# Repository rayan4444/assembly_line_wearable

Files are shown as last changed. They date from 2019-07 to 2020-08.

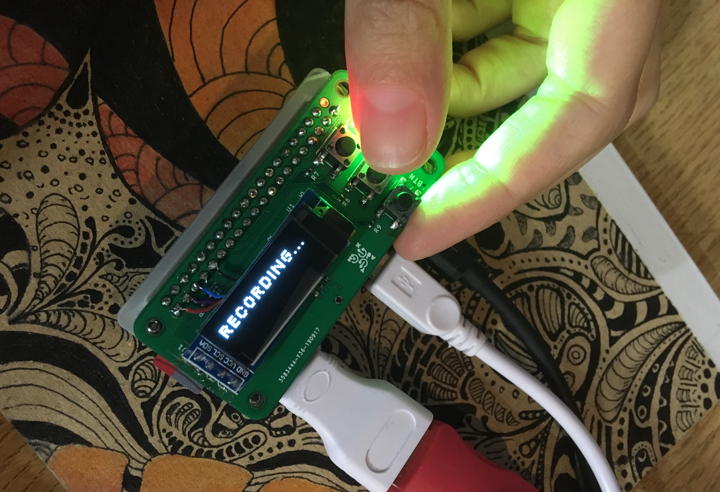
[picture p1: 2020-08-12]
assets/Crimson_testing_2.jpg

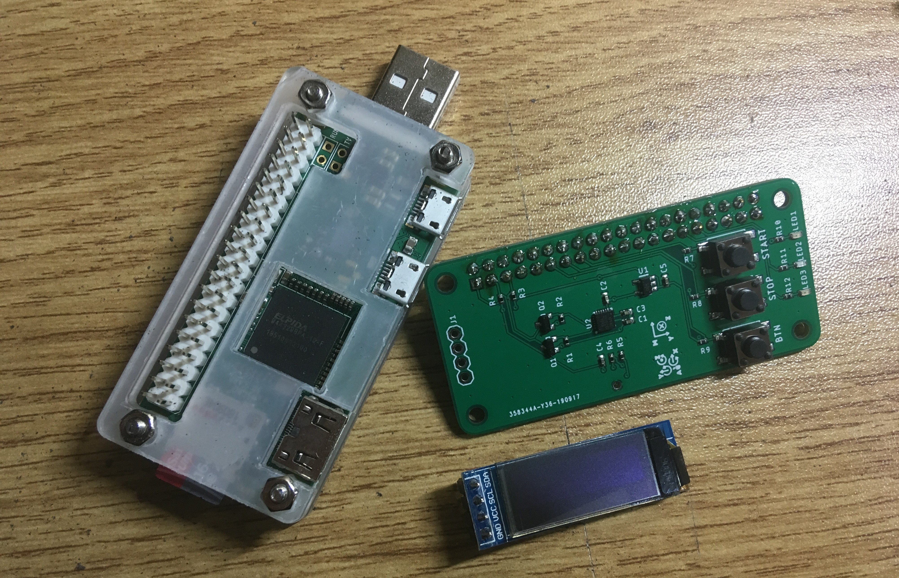
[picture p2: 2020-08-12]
assets/Crimson_testing_3.jpg

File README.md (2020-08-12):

# Crimson Dynamic

Hardware files and code for Crimson Dynamic (HAX Shenzhen 2019) sensor system prototyping

## Objective
Design a sensor system that adds value to the exoskeleton, specifically for use in an overhead assembly line in car factories. Potential insights the sensor system could provide:
* Task compliance: ensure a worker did not forget a bolt/nut on a car
* long term vibration exposure
* long term arm fatigue
* long term noise exposure
 * etc.

## REV 1
Sensor breakout to count the number of overhead drilling actions accomplished. Looked into doing an FFT analysis on IMU data and microphone data. Decided to settle on matching IMU data peaks to microphone data peaks. The same two sensors could be use to quantify the long term exposure to vibration, noise and fatigue.

## REV2
Pi HAT with sensors and UI to count the number of overhead drilling actions accomplished. A more efficient rendition of REV1 that is usable for demonstration.
> Note: Data is post processed and results are not given in real time

## REV3
NRF52 based sensor node with only IMU to monitor limb motion and vibration

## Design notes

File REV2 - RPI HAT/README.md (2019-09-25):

Crimson Dynamics REV2

## Description
Pi HAT with sensors and UI to count the number of overhead drilling actions accomlished:
- 1 x ICM20948 9-Dof IMU 
- 1 x SPH0645LM4H MEMS Microphone
- 3 x pushbuttons
- 2 x LEDs
- 1 x 128x32 I2C OLED Display 
- 1 x Raspberry Pi Zero W v1.1

#### Python scripts
Crimson_button.py runs at boot and imports functions from Crimson_data_log.py and Crimson_action_count.py

#### Usage:
- Boot up the Rasberry Pi and wait for the OLED display to refresh. This might take up to 3-4 min.  
- Pressing "start" button records 40s of data from the microphone and the IMU (x,y,z acceleration to be specific). 
- Green LED lights up and stays on after the recording is done if everything went well 
- Pressing "stop" button analyses results, using the latest action counting technique from rev1.
> By default plotting is not enabled because it slows everything down and requires a way to close the plot window to proceed. but in case it is needed, plt.show() can be uncommented from Crimson_action_count.py
- Orange LED lights up and stays on after processing is done if everything went well. The final count will show on the display for a couple seconds. 
- Pressing "BTN" button deletes all data records. If you want to keep the recorded data, ssh into the Rpi and copy it to another directory before deleting it. 
> If you don't delete the data, the next recording will just be appended to the current file and give false action count results. 

#### Notes: 
- Display breakout on the PCB doesn't match the module we purchsed so some reworking had to be done to be able to wire it properly 
- A single python script that can be run from boot. It imports functions from two other python files. These functions are very similar to the REV1 code, a little has been done to optimise it. 
- To view code outputs you can hook up a display to the pi or ssh into it (or use VNC). You can also uncomment print statements in the code to track the action countinfg process. 
- [Tutorial to change microphone sensitivity](https://learn.adafruit.com/adafruit-i2s-mems-microphone-breakout/raspberry-pi-wiring-and-test)

## Hardware files
Eagle files and gerber files for the Pi HAT

## Other files
* Notes from meeting with Bunnie on 24.09.2019, discussing how to go about improving the current demo and going about the next version

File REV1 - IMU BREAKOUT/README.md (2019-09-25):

Crimson Dynamics REV1

## Decription
Tries to detect drilling acitons by matching accelerometer peaks to microphone peaks. 
- Attempted doing it purely by placing the IMU on the hand holding the drill and running FFT but as the body acted as a low pass filter and filetered out higher frequencies that could have had information to characterise drilling vibrations. 
- Decided to addd a microphone to provide a second input. 
- In the final iteration of REV1, a simple peak finding algorithm from signal.scipy library is used to identify peaks in accelration and microphone recording. If the peaks happen within a second from each other they are assumed to belong to the same drilling action. Assuming the worker only does drilling tasks, this can be used to count the number of tasks. 

#### Notes:
- detailed assumptions in code
- sigle movements (vs vibrations) are not counted as drilling motion reducing false positives. 
- the code is in different scripts and run very slowly. 

## Hardware files 
ICM20948 breakout board slightly modified from the [Sparkfun one](https://www.sparkfun.com/products/15335)
## Python scripts 
#### Crimson_data_log.py
Records 10s of IMU and Microphone data, saves it in files "sensor_log.csv" and "output.wav" respectively. Later splits sensor log in "ax.csv", "ay.csv" and "az.csv" for further analysis. 

#### Crimson_action_count.py
- Opens data files and runs peak finding algorithm 
- Plots peaks found 
- For each of ax, ay, az and mic data, groups peaks that are within 0.5 seconds of each other as belonging to one "action" 
- To reduce the occurrance of false positives, only considers "actions" with peaks in at least two of the 3 accelerometer axes. 
- Only Counts "actions" with peaks in both microphone and accelerometer data (peak cluster averages within 1s of each other) 
- Prints total numberof valid "actions"

## OLD CODE
All the other python scripts used to test various things, such as IMU and microphone recording, data hadnling and plotting, FFT analysis etc. 

## TEST DATA
Data recorded with the prototype and used to tweak the peak finidng algorithm. TEST 5 is the best. 
In this version:
- 1 x ICM20948 9-Dof IMU (Eagle files for the breakout board are in this folder) 
- 1 x SPH0645LM4H MEMS Microphone breakout (from taobao)
- 1x Raspberry Pi (Raspberry Pi Zero W v1.1 used in my tests)

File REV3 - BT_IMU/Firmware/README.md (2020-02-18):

# Programming Guide
Notes and steps to follow to easily program the CRIMSON_IMU_BT board.

## Pinout
| Signal | NRF52 Pin |
|:---:|:---:|
|LED_R|P0.13|
|LED_G|P0.15|
|LED_B|P0.17|
|SCL|P.019|
|SDA| P0.18|
|IMU_INT|P0.25|
|SPI_MOSI|P0.27|
|SPI_MISO|P0.26|
|SPI_SCK|P0.28|
|SPI_CS|P0.29|
|CARD_DETECT|P0.23|
|TX|P0.06|
|RX|P0.08|
|CTS|P0.07|
|RTS|P0.05|
|BAT_SENSE|AIN6/P0.30|
|BUTTON|P0.14|
|RESET|P0.21|

## Flash and Debug setup
Follow the [tutorial](https://gitlab.com/hax_eng/hax-open/vs_code_setup_tutorials/tree/master/NRF52) to setup your development environment if you haven't already.
> I use ARMGCC and GDB to compile and debug, but you can choose an entirely different setup

#### Using the NRF52 Development kit to program a custom board
You can use the onboard J-link adapter of the NRF52 Development Kit to program your custom board.

**Connections**

|NRF52 Dev Kit| Custom PCB|
|:---:|:---:|
|VTG|3V3|
|SWDIO|SWDIO|
|SWCLK|SWCLK|
|GND|GND|
|RESET*|RESET*|

\* Optional
>Make sure you power your Custom board from an external source. The VTG connection  from the Dev Kit does not power the board, it just detects the target voltage.

## Directions of use
* Power on or reset device: a pink LED will stay on until you connect and pair with a Bluetooth host (ex: your smartphone. you can use NRFconnect mobile app).
* Once the device is connected and paired, the light will turn blue. 
* Stand in a neutral position with the arm down. Press the button to calibrate the device: this will sync time and record gyro offsets. 
* Once the device is calibrated, you can go a head and use it: it will log "up" and "down" events in the SD card. 

## Feature implementation
Already implemented:
* BLE connection
* Time sync
* Reading sensor data
* Processing sensor data (Madgwick filter) to determine orientation
* Logging "up" (event type 1) and "down"  (event type 0) events with timestamp
* Writing events to SD card
* Reading battery ADC

To be implemented:
* Read SD card file over UART
* Read SD card file over BLE
* Monitor battery charging 
* Battery level service over BLE

Notes:
* The device updates roll pitch and yaw angles with reference to earth gravity so you can create more event types by defining specific angle thresholds. 

## Errata

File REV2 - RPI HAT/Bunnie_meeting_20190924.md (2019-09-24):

# Crimson <> Bunnie meeting (24/09/2019)

## How to improve python running on Rpi zero (faster, less resource intensive)
* Pickling (https://pythontips.com/2013/08/02/what-is-pickle-in-python/)
* Microphone: Reduce sample count to 8kHz for microphone, record in mono
* Pre-compile python

Basically spend a bunch of time optimising your python code.

## Real time? 
Live counting with python: if you do live stream processing you need at least 2 cores, one for sampling , one for processing)

## If you want to add AI for fanciness: 
* Google AI kit: https://www.blog.google/technology/ai/introducing-aiy-vision-kit-make-devices-see/
* Pi HAT format train drill sound as a “attention word” 
* You can train it on different tools (microphone data and maybe even IMU?)

## IOT approach vs processing everythign locally 
* everything on the glove, it’s self contained: porting python to a more contained MCU might be difficult, strong-ish processor needed that's going to be on the more expensive side. 

vs 

* ioT : (more potential problems having a whole server infrastructure, antenna/electrical interference etc….)> hidden costs. So if your team is not especially strong in IOT going that route is not recommended. It might end up costing you a lot more than the self contained solution

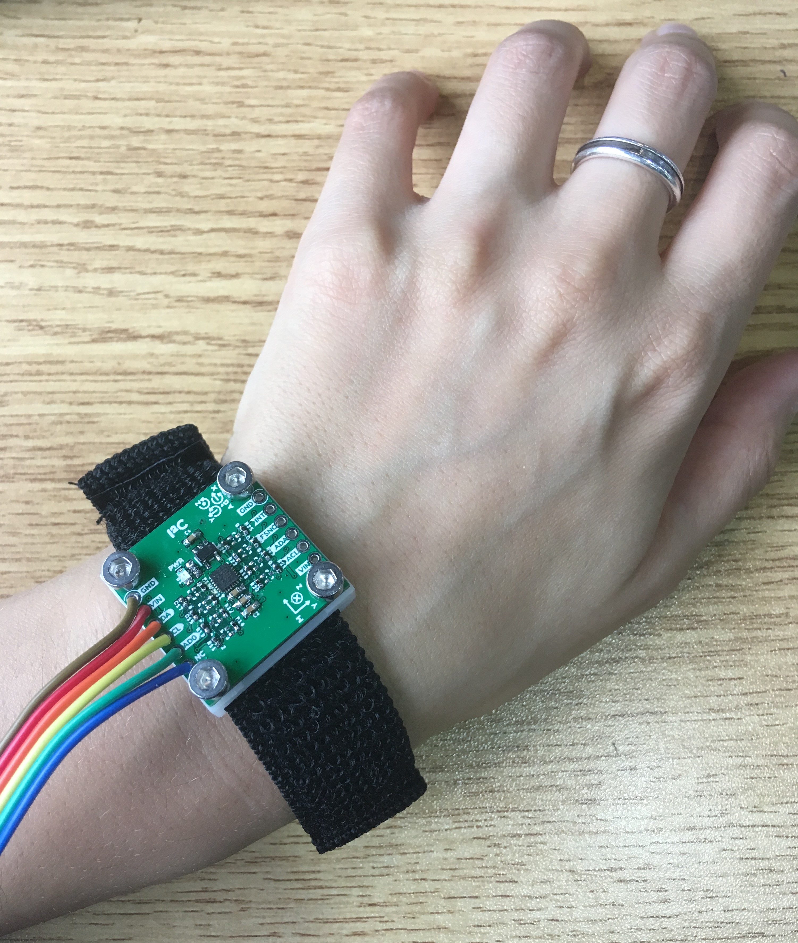
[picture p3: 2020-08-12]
assets/Crimson_breakout_1.jpg

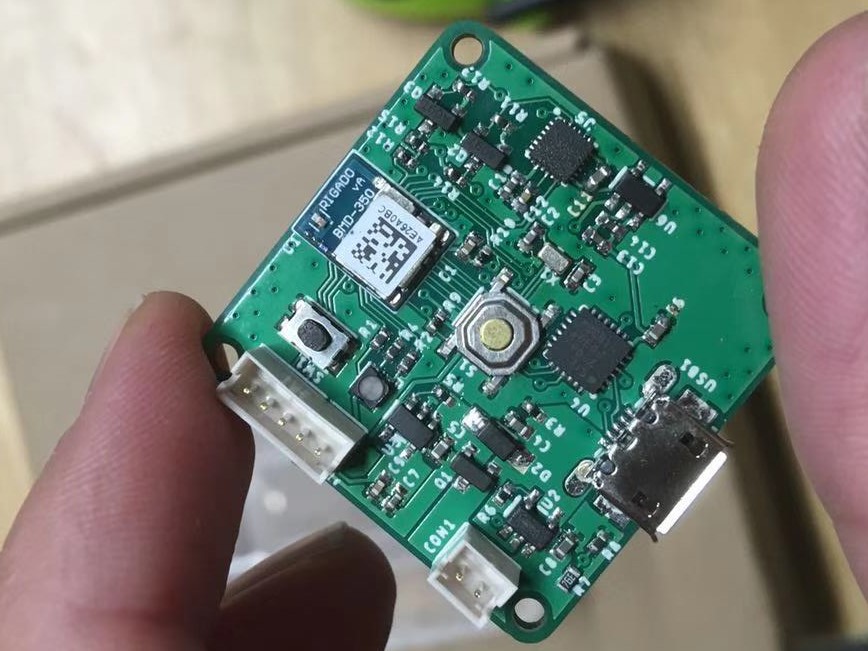
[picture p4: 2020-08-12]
assets/bt_imu.jpg

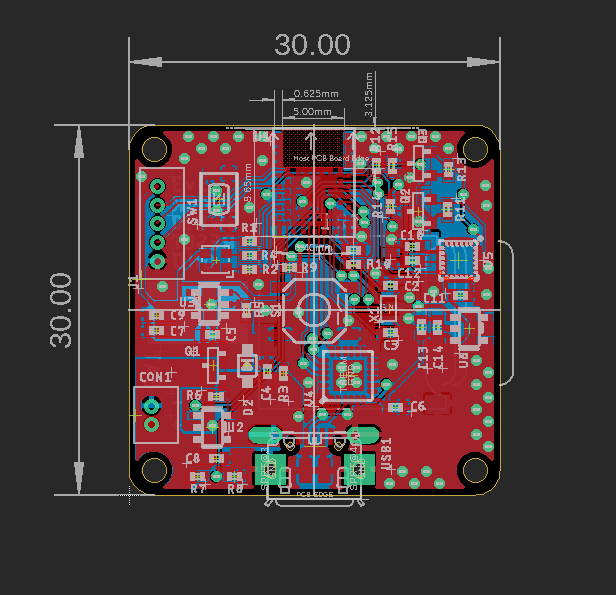
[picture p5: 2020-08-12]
assets/layout.png

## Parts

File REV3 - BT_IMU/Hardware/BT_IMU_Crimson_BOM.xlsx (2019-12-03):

Crimson BT_IMU BOM
# | Parts | Value | Qty | Package | Description | Link
1 | C1, C9, C11, C12 | 100nF | 4 | C0402 | Ceramic Capacitor | https://item.szlcsc.com/107424.html
2 | C2, C3 | 22pF | 2 | C0402 | Ceramic Capacitor | https://item.szlcsc.com/1907.html
3 | C4, C5, C6, C8 | 10uF | 4 | C0402 | Ceramic Capacitor | https://item.szlcsc.com/88326.html
4 | C7, C10, C13, C14 | 1uF | 4 | C0402 | Ceramic Capacitor | https://item.szlcsc.com/93949.html
5 | R1, R2, R4 | 100R | 3 | R0402 | Resistor | https://item.szlcsc.com/25881.html
6 | R6 | 2k | 1 | R0402 | Resistor | https://item.szlcsc.com/399955.html
7 | R7 | 6M | 1 | R0402 | Resistor | https://item.szlcsc.com/415864.html
8 | R8 | 2.2M | 1 | R0402 | Resistor | https://item.szlcsc.com/26832.html
9 | R3, R5 | 100k | 2 | R0402 | Resistor | https://item.szlcsc.com/107449.html
10 | R9, R10, R12 | 10k | 3 | R0402 | Resistor | https://item.szlcsc.com/103974.html
11 | R11, R13, R14, R15 | 4.7k | 4 | R0402 | Resistor | https://item.szlcsc.com/26683.html
12 | D1 | B2020RGBA | 1 | B2020RGBA | RGB LED | https://item.szlcsc.com/110013.html
13 | D2 | MBR120 | 1 | SOD-123 | Schottky Diode | https://item.szlcsc.com/142169.html
14 | Q1 | DMG2305 | 1 | SOT-23 | P-Channel MOSFET | https://item.szlcsc.com/161808.html
15 | Q2, Q3 | AO3400 | 2 | SOT-23 | N-Channel MOSFET | https://item.szlcsc.com/421500.html
16 | X1 | ECX-12L or ABS06L | 1 | 2.0X1.2 | Tuning Fork Crystals (kHz) SMD:
17 | U1 | BMD-350 | 1 | BMD-350 | BMD-350
18 | U2 | MCP73831T-2ACI/OT | 1 | SOT23-5 | MCP73831/2 LIPO Charger | https://item.szlcsc.com/15551.html
19 | U3 | AP2112K-3.3TRG1 | 1 | SOT23-5 | 3.3V Fixed Voltage Regulator | https://item.szlcsc.com/52131.html
20 | U4 | CP2104 | 1 | QFN24_4MM_SMSC | USB to UART Bridge | https://item.szlcsc.com/48747.html
21 | U5 | ICM-20948 | 1 | QFN24-3X3 | 9 Degree of Freedom IMU
22 | U6 | TLV70018DDCR | 1 | MICROBUILDER_SOT23-5 | 1.8V Fixed Linear Voltage Regulator | https://item.szlcsc.com/81068.html
23 | SW1 | TS5215A 250gf | 1 | MICROBUILDER_BTN_KMR2_4.6X2.8 | Tact Switch | https://item.szlcsc.com/363186.html
24 | S1 | KMR2 | 1 | TACTILE_SWITCH_SMD_5.2MM | Tact Switch | https://item.szlcsc.com/73554.html
25 | USB1 | U254-051N-4BHJ233-S | 1 | 4UCONN_20329_V2 | USB Connectors | https://item.szlcsc.com/300259.html
26 | CON1 | B2B-ZR | 1 | B2B-ZR | JST-ZH Connector, 2Pin | https://item.szlcsc.com/174414.html
27 | J1 | B5B-ZR | 1 | B5B-ZR | JST-ZH Connector, 5 Pin | https://item.szlcsc.com/255573.html
28 | SD1 | 2908-05WB-MG | 1 | MICROSD | Micro-SD / Transflash card holder with SPI pinout | https://item.taobao.com/item.htm?id=532902605150
29 | N.A. | LiPo Battery | 1 | Lipo Battery |  | (with ZH1.25 connector) https://item.taobao.com/item.htm?id=41411659259

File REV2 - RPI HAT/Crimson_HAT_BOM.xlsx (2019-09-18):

# | Parts | Value | Qty | Package
1 | C2, C3 | 100nF | 2 | C0402 | https://item.szlcsc.com/287818.html
2 | C1, C4, C5 | 1uF | 3 | C0402 | https://item.szlcsc.com/53938.html
3 | R10, R11, R12 | 100R | 3 | R0402 | no need to buy
4 | R5, R7, R8, R9 | 10k | 4 | R0402 | https://item.szlcsc.com/26274.html
5 | R1, R2, R3, R4 | 2.2k | 4 | R0402 | no need to buy
6 | R6 | 68R | 1 | R0402 | https://item.szlcsc.com/101732.html
7 | U2 | ICM-20948 | 1 | QFN24-3X3 | https://detail.tmall.com/item.htm?id=597841363170
8 | Q1, Q2 | AO3400 | 2 | SOT-23 | https://item.szlcsc.com/192487.html
9 | LED3 | GREEN | 1 | CHIPLED_0603 | https://item.szlcsc.com/119599.html
11 | LED2 | RED | 1 | CHIPLED_0603 | https://item.szlcsc.com/193260.html
10 | IC1 | MIC_I2S_SPH0645 | 1 | SPH0645LM4H | https://item.taobao.com/item.htm?id=555562766149
13 | SW1, SW2, SW3 | SPST_TACT-EVQQ2 | 3 | EVQ-Q2 | no need to buy
14 | U1 | TLV70018DDCR | 1 | SOT23-5 | https://item.szlcsc.com/81068.html
 | SCREEN: |  |  |  | https://item.taobao.com/item.htm?id=558142276427

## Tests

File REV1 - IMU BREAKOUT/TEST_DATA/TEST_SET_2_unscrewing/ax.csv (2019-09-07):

Ax
0.93798828125
0.9345703125
0.93359375
0.92919921875
0.93603515625
0.93505859375
0.9638671875
0.935546875
0.95703125
0.97607421875
1.00244140625
1.015625
0.99365234375
1.03271484375
0.970703125
0.97802734375
1.1083984375
1.0576171875
0.96826171875
0.94970703125
0.95263671875
0.9208984375
0.80712890625
0.97509765625
0.919921875
0.8486328125
0.7021484375
0.619140625
0.67578125
0.654296875
0.69091796875
0.73974609375
0.7314453125
0.6904296875
0.66015625
0.576171875
0.55419921875
0.60693359375
0.60205078125
0.53857421875
0.59521484375
0.6015625
0.56787109375
0.546875
0.50439453125
0.548828125
0.599609375
0.59326171875
0.53955078125
0.52392578125
0.4912109375
0.46533203125
0.4443359375
0.5126953125
0.5400390625
0.38232421875
0.41748046875
0.37548828125
0.4521484375
0.4892578125
0.44921875
0.42138671875
0.4130859375
0.4052734375
0.478515625
0.3603515625
0.4267578125
0.41552734375
0.3779296875
0.43701171875
0.4296875
0.4287109375
0.43359375
0.4111328125
0.43896484375
0.130859375
0.26025390625
0.29736328125
0.115234375
0.02685546875
0.32275390625
0.30126953125
0.28271484375
0.21923828125
0.3212890625
0.35888671875
0.146484375
0.4599609375
0.54931640625
0.24365234375
0.34619140625
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

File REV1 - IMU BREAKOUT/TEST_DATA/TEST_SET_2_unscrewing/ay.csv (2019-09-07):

Ay
-0.08154296875
-0.07958984375
-0.08447265625
-0.08203125
-0.080078125
-0.08984375
-0.0830078125
-0.0947265625
-0.06396484375
-0.0771484375
-0.072265625
-0.0810546875
-0.0849609375
-0.08740234375
-0.0791015625
-0.0791015625
-0.068359375
-0.10888671875
-0.11865234375
-0.125
-0.1376953125
-0.1240234375
-0.14208984375
-0.09716796875
-0.0927734375
-0.103515625
-0.0595703125
0.0205078125
0.00390625
0.06396484375
0.06103515625
0.08203125
0.07470703125
0.1103515625
0.07421875
0.10009765625
0.11474609375
0.1337890625
0.1396484375
0.1787109375
0.1953125
0.19189453125
0.1640625
0.16015625
0.18017578125
0.1865234375
0.193359375
0.20947265625
0.22509765625
0.216796875
0.208984375
0.2177734375
0.24755859375
0.15576171875
0.23388671875
0.19775390625
0.20703125
0.21923828125
0.208984375
0.2314453125
0.21923828125
0.2373046875
0.2255859375
0.25048828125
0.255859375
0.34326171875
0.23974609375
0.23779296875
0.2734375
0.25390625
0.27392578125
0.208984375
0.21826171875
0.2177734375
0.1123046875
0.46875
0.18896484375
0.27734375
0.2890625
0.384765625
0.50830078125
0.4853515625
0.5546875
0.45556640625
0.48583984375
0.40771484375
0.43896484375
0.51318359375
0.5234375
0.37353515625
0.390625
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

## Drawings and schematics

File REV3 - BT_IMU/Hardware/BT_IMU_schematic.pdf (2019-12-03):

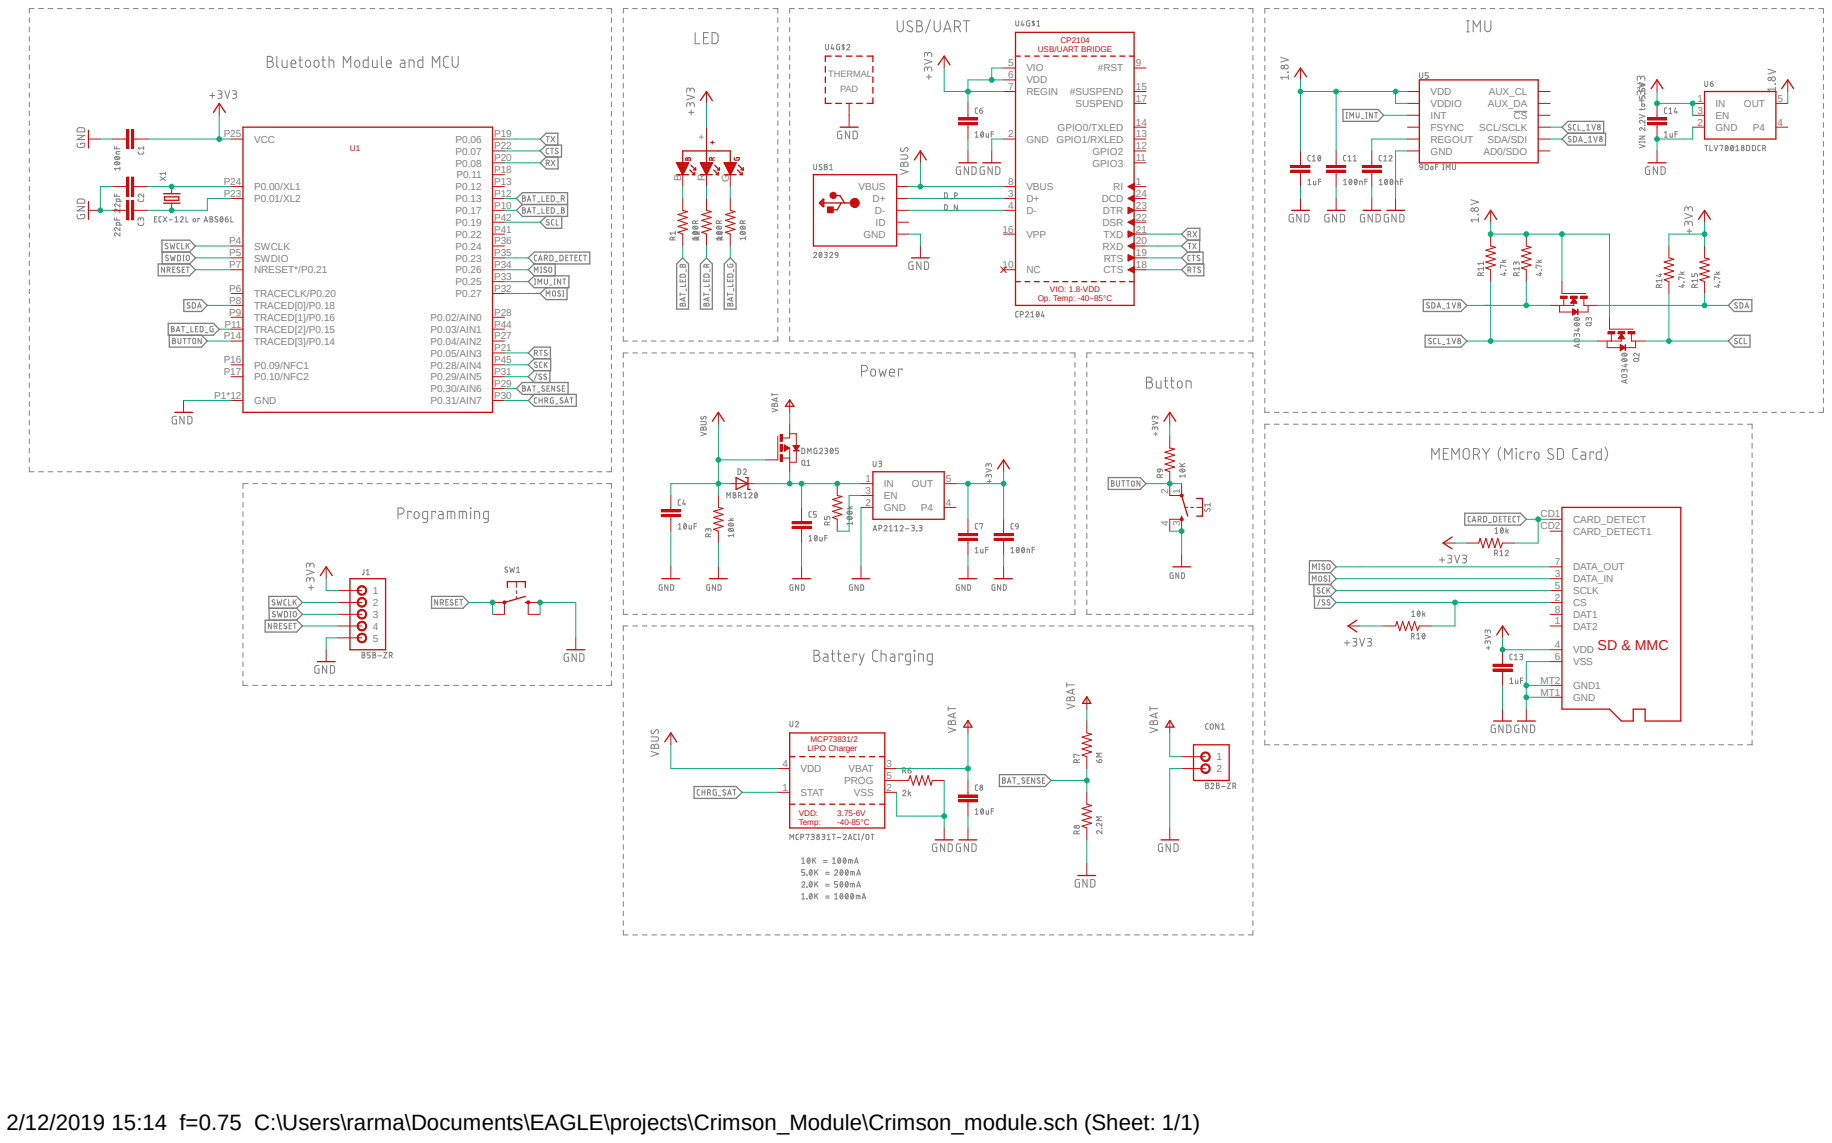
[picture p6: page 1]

2/12/2019 15:14 f=0.75 C:\Users\rarma\Documents\EAGLE\projects\Crimson_Module\Crimson_module.sch (Sheet: 1/1)

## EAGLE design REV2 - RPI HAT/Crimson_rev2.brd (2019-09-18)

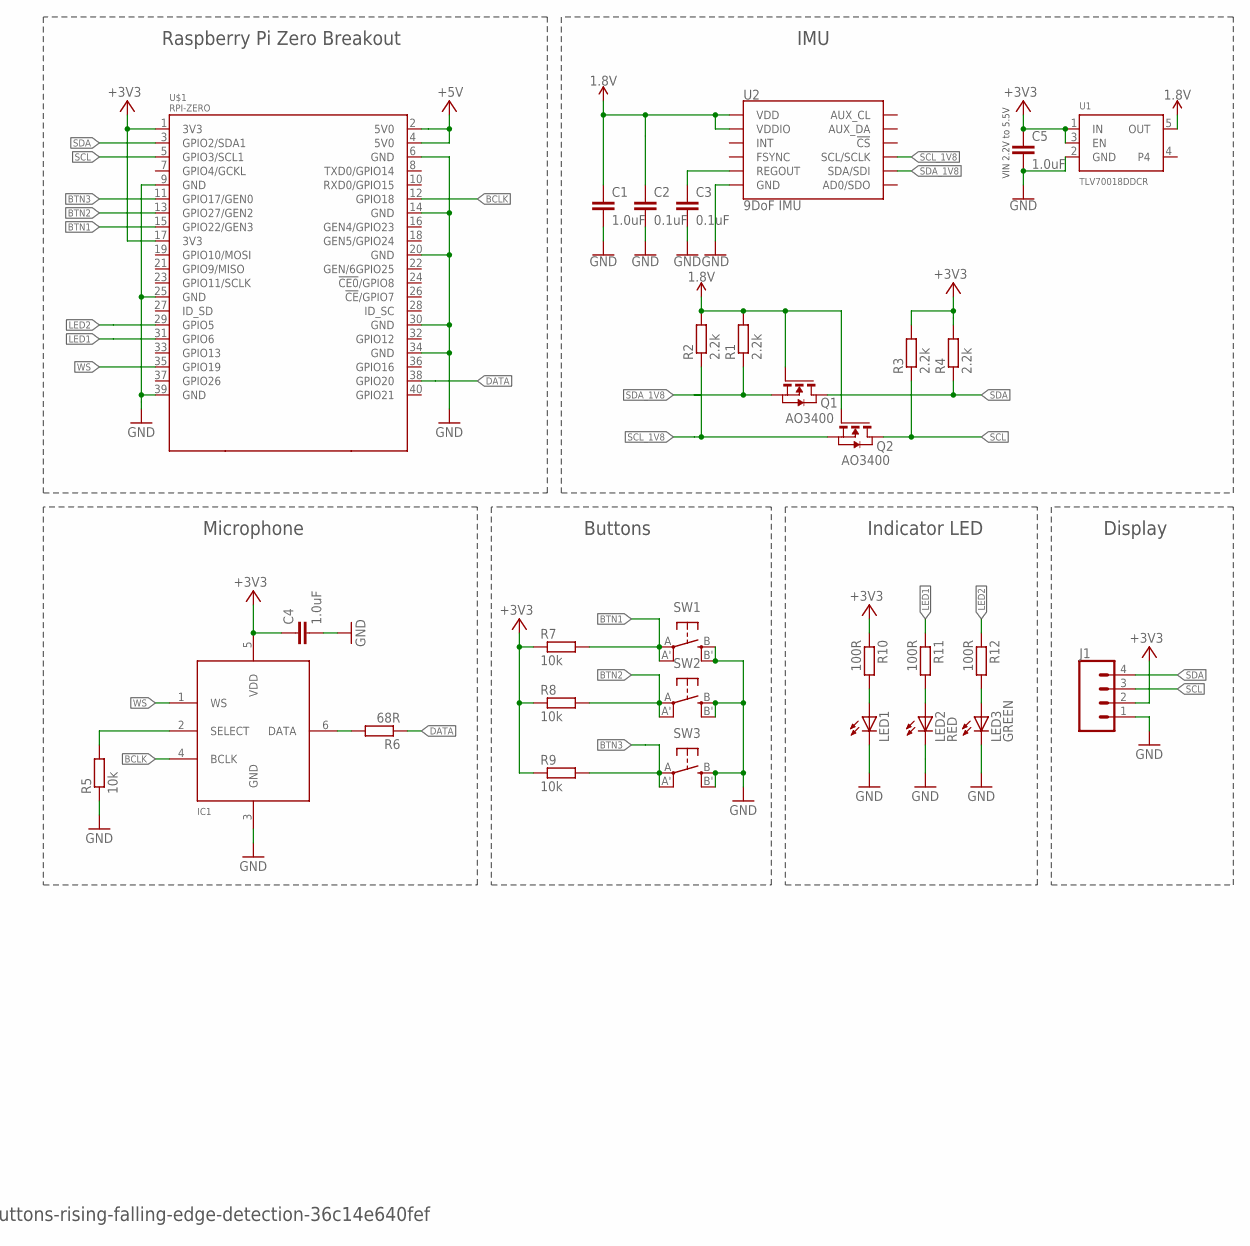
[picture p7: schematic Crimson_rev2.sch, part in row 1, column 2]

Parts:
C1, C4, C5: 1.0uF; 0402
C2, C3: 0.1uF; 0402
IC1: MIC_I2S_SPH0645; SPH0645LM4H
J1: CONN_04; 1X04
LED1: LEDCHIPLED_0603; CHIPLED_0603
LED2: RED; CHIPLED_0603
LED3: GREEN; CHIPLED_0603
Q1, Q2: AO3400; SOT-23
R1, R2, R3, R4: 2.2k; R0402
R5, R7, R8, R9: 10k; R0402
R6: 68R; R0402
R10, R11, R12: 100R; R0402
SW1, SW2, SW3: SPST_TACT-EVQQ2; EVQ-Q2
U1: TLV70018DDCR; MICROBUILDER_SOT23-5
U2: 9DoF IMU; QFN24-3X3
U$1: RPI-ZERO; RASPBERRYPI_BASTELSTUBE_V13_RASPI_BOARD_B+_FULL

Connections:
1.8V: C1.1, C2.1, Q1.G, Q2.G, R1.2, R2.2, U1.5 (OUT), U2.8 (VDDIO), U2.13 (VDD)
+3V3: C4.1, C5.1, IC1.5 (VDD), J1.2, R3.2, R4.2, R7.2, R8.2, R9.2, R10.1, U1.1 (IN), U1.3 (EN), U$1.1 (3V3), U$1.17 (3V3)
+5V: U$1.2 (5V0), U$1.4 (5V0)
BCLK: IC1.4 (BCLK), U$1.12 (GPIO18)
BTN1: R7.1, SW1.A, SW1.A' (P1), U$1.15 (GPIO22/GEN3)
BTN2: R8.1, SW2.A, SW2.A' (P1), U$1.13 (GPIO27/GEN2)
BTN3: R9.1, SW3.A, SW3.A' (P1), U$1.11 (GPIO17/GEN0)
DATA: R6.1, U$1.38 (GPIO20)
GND: C1.2, C2.2, C3.2, C4.2, C5.2, IC1.3 (GND), J1.1, LED1.C, LED2.C, LED3.C, R5.1, SW1.B (S), SW1.B' (S1), SW2.B (S), SW2.B' (S1), SW3.B (S), SW3.B' (S1), U1.2 (GND), U2.18 (GND), U2.20 (GND), U$1.6 (GND), U$1.9 (GND), U$1.14 (GND), U$1.20 (GND), U$1.25 (GND), U$1.30 (GND), U$1.34 (GND), U$1.39 (GND)
LED1: R11.1, U$1.31 (GPIO6)
LED2: R12.1, U$1.29 (GPIO5)
unnamed: C3.1, U2.10 (REGOUT)
unnamed: IC1.2 (SELECT), R5.2
unnamed: IC1.6 (DATA), R6.2
unnamed: LED1.A, R10.2
unnamed: LED2.A, R11.2
unnamed: LED3.A, R12.2
SCL: J1.3, Q2.D, R3.1, U$1.5 (GPIO3/SCL1)
SCL_1V8: Q2.S, R2.1, U2.23 (SCL/SCLK)
SDA: J1.4, Q1.D, R4.1, U$1.3 (GPIO2/SDA1)
SDA_1V8: Q1.S, R1.1, U2.24 (SDA/SDI)
WS: IC1.1 (WS), U$1.35 (GPIO19)

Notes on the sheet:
IMU
Microphone
Buttons
Display
Indicator LED
Reference: https://medium.com/@rxseger/interrupt-driven-i-o-on-raspberry-pi-3-with-leds-and-pushbuttons-rising-falling-edge-detection-36c14e640fef
VIN 2.2V to 5.5V
Raspberry Pi Zero Breakout

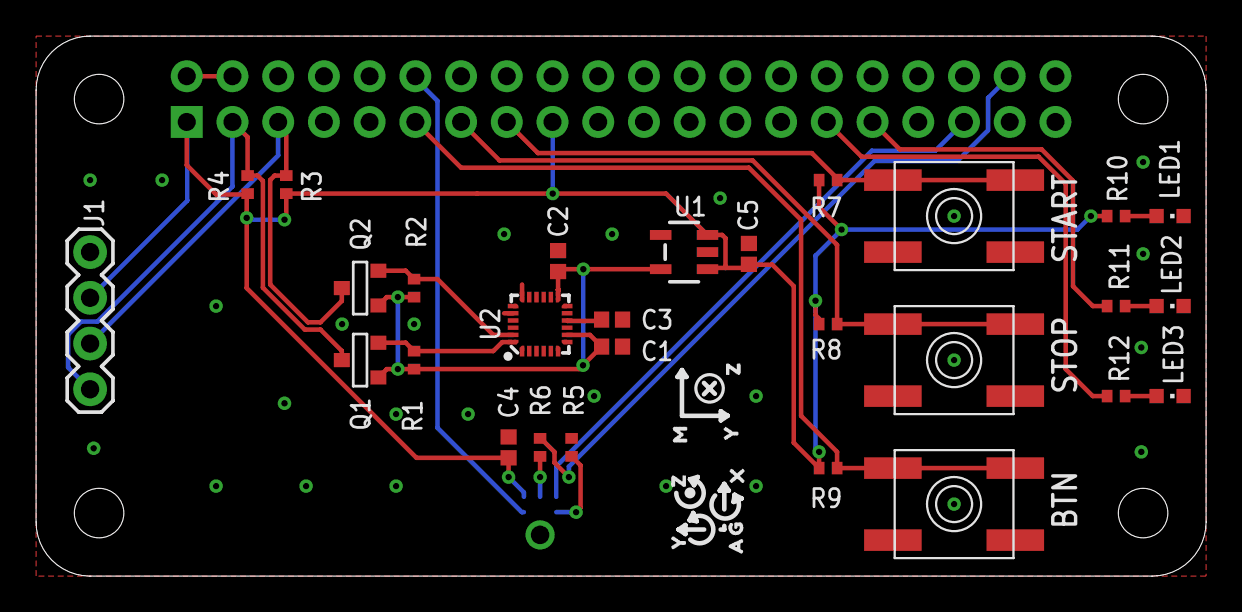
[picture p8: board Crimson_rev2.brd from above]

Board: 2 copper layers, 65.0 x 30.0 mm, 38 parts (1 on the bottom side), 22 nets.

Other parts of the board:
U$34: X0
U$35, U$41: Y1
U$36, U$42: Z2
U$37: G5
U$38: A4
U$39: M3

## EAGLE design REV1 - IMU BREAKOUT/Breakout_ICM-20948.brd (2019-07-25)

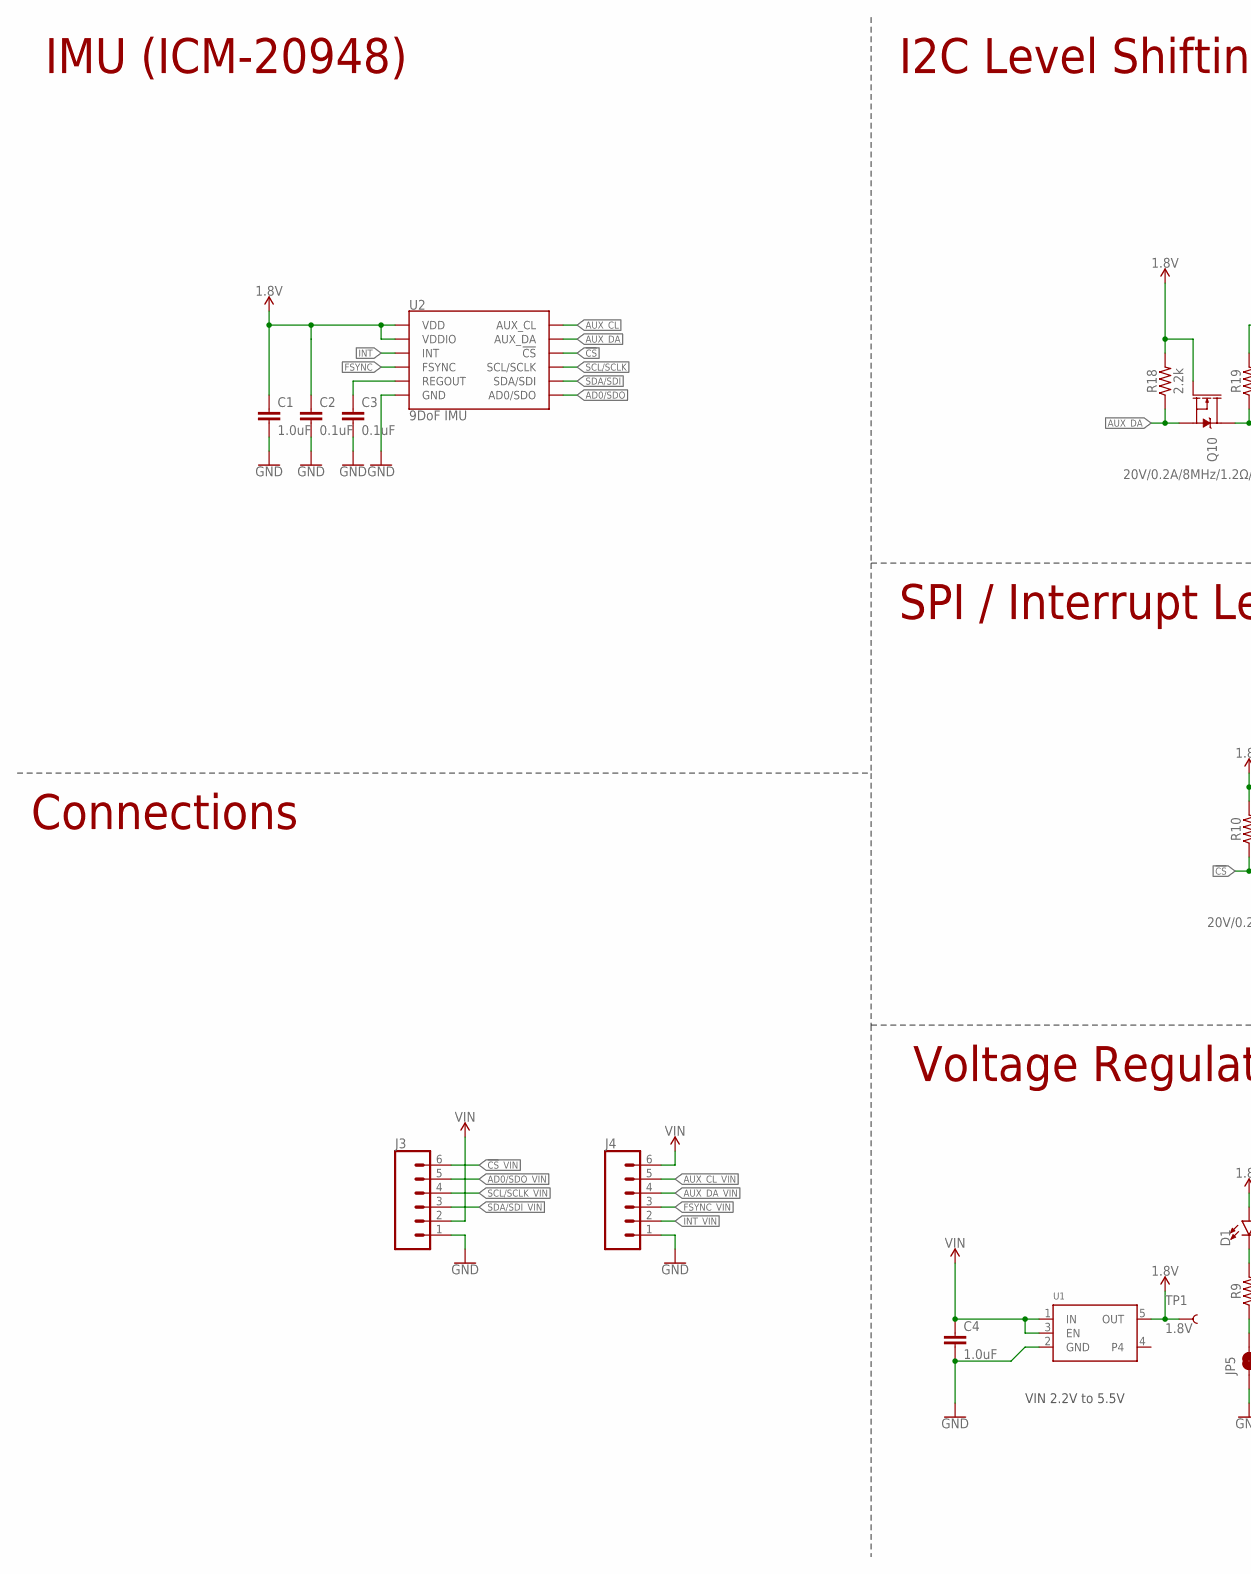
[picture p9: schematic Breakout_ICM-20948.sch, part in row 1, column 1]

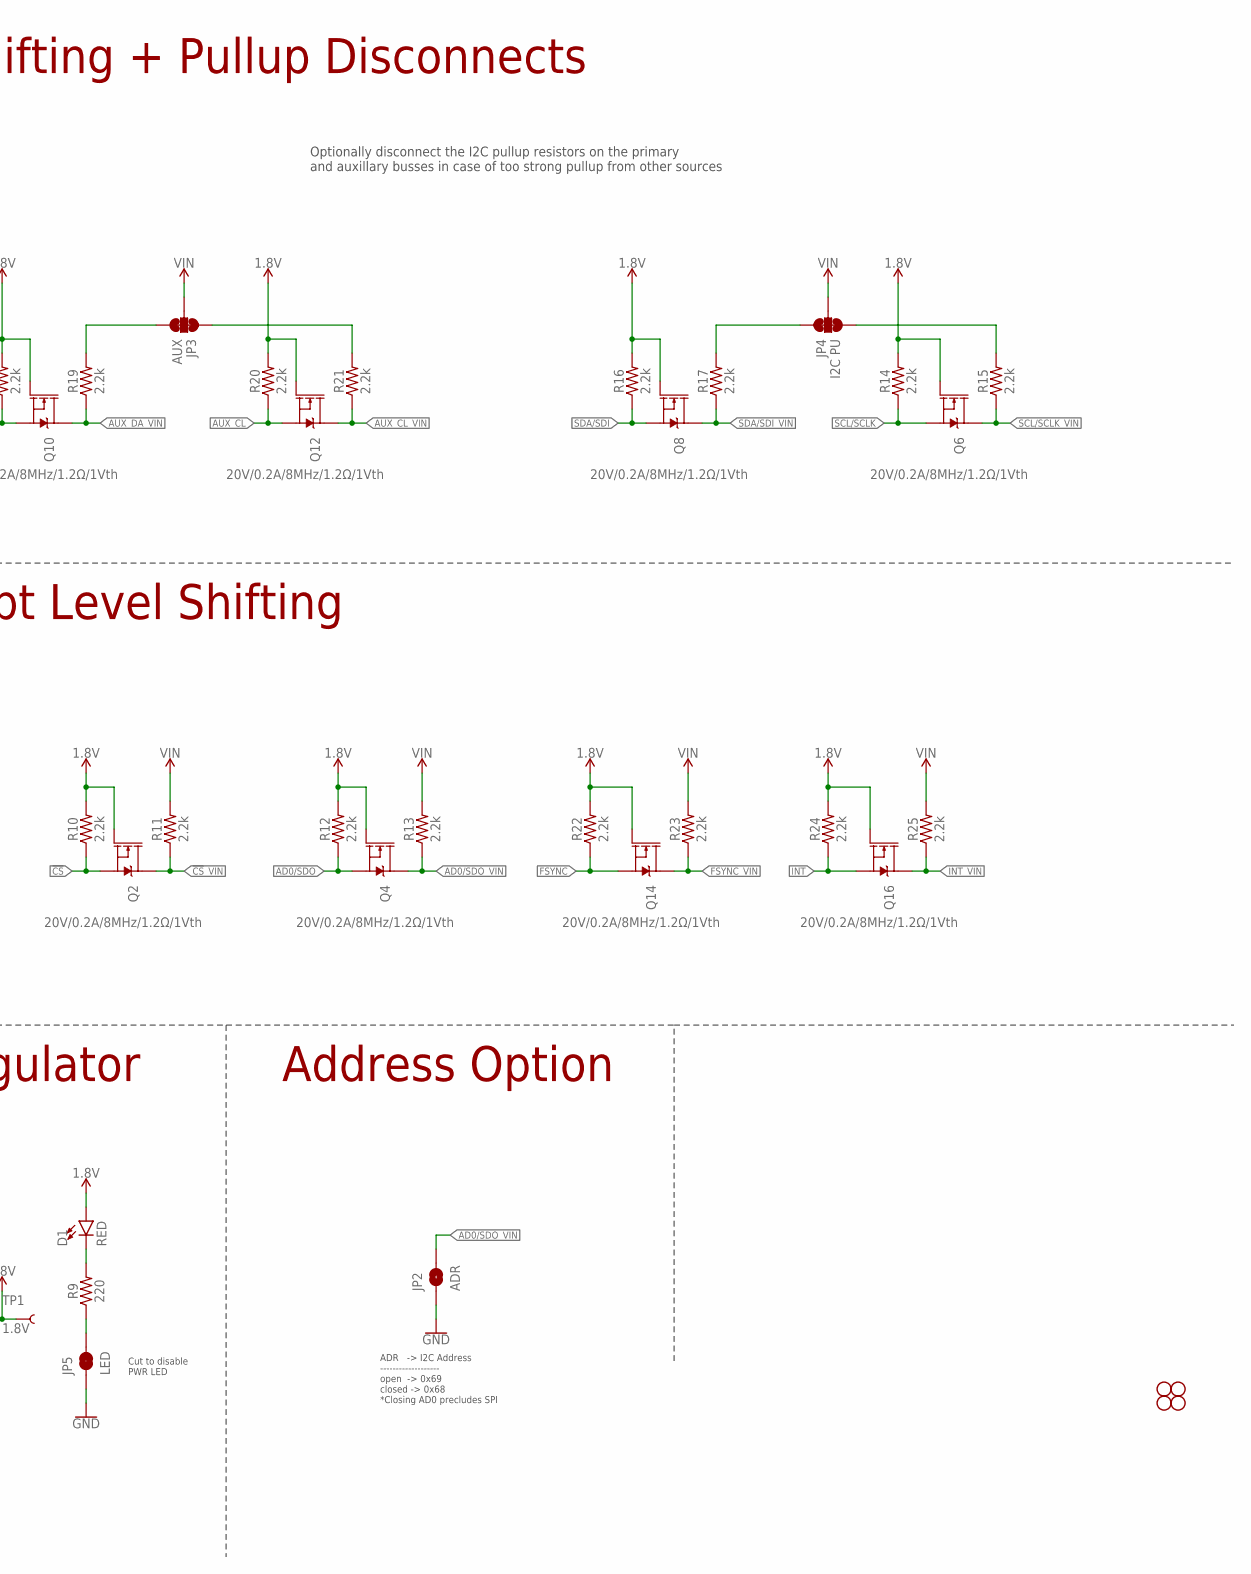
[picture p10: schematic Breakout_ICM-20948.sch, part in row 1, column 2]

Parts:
C1, C4: 1.0uF; 0603
C2, C3: 0.1uF; 0603
D1: RED; LED-0603
H1, H2, H3, H4: STAND-OFF
J3, J4: CONN_06NO_SILK_NO_POP; 1X06_NO_SILK
JP2: ADR; SMT-JUMPER_2_NO_SILK
JP3: AUX; SMT-JUMPER_3_2-NC_TRACE_SILK
JP4: I2C PU; SMT-JUMPER_3_2-NC_TRACE_SILK
JP5: LED; SMT-JUMPER_2_NC_TRACE_SILK
Q2, Q4, Q6, Q8, Q10, Q12, Q14, Q16: 20V/0.2A/8MHz/1.2Ω/1Vth; SOT-416FL
R9: 220; 0603
R10, R11, R12, R13, R14, R15, R16, R17, R18, R19, R20, R21, R22, R23, R24, R25: 2.2k; 0402-TIGHT
TP1: 1.8V; PAD.03X.03
U1: MICROBUILDER_VREG_SOT23-5; MICROBUILDER_SOT23-5
U2: 9DoF IMU; QFN24-3X3

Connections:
1.8V: C1.1, C2.1, D1.A, Q2.1 (G), Q4.1 (G), Q6.1 (G), Q8.1 (G), Q10.1 (G), Q12.1 (G), Q14.1 (G), Q16.1 (G), R10.2, R12.2, R14.2, R16.2, R18.2, R20.2, R22.2, R24.2, TP1.P$1, U1.5 (OUT), U2.8 (VDDIO), U2.13 (VDD)
!CS: Q2.2 (S), R10.1, U2.22 (!CS)
!CS!_VIN: J3.6, Q2.3 (D), R11.1
AD0/SDO: Q4.2 (S), R12.1, U2.9 (AD0/SDO)
AD0/SDO_VIN: J3.5, JP2.2, Q4.3 (D), R13.1
AUX_CL: Q12.2 (S), R20.1, U2.7 (AUX_CL)
AUX_CL_VIN: J4.5, Q12.3 (D), R21.1
AUX_DA: Q10.2 (S), R18.1, U2.21 (AUX_DA)
AUX_DA_VIN: J4.4, Q10.3 (D), R19.1
FSYNC: Q14.2 (S), R22.1, U2.11 (FSYNC)
FSYNC_VIN: J4.3, Q14.3 (D), R23.1
GND: C1.2, C2.2, C3.2, C4.2, J3.1, J4.1, JP2.1, JP5.1, U1.2 (GND), U2.18 (GND), U2.20 (GND)
INT: Q16.2 (S), R24.1, U2.12 (INT)
INT_VIN: J4.2, Q16.3 (D), R25.1
unnamed: C3.1, U2.10 (REGOUT)
unnamed: JP4.3, R15.2
unnamed: JP4.1, R17.2
unnamed: JP3.1, R21.2
unnamed: JP3.3, R19.2
unnamed: D1.C, R9.2
unnamed: JP5.2, R9.1
SCL/SCLK: Q6.2 (S), R14.1, U2.23 (SCL/SCLK)
SCL/SCLK_VIN: J3.4, Q6.3 (D), R15.1
SDA/SDI: Q8.2 (S), R16.1, U2.24 (SDA/SDI)
SDA/SDI_VIN: J3.3, Q8.3 (D), R17.1
VIN: C4.1, J3.2, J4.6, JP3.2, JP4.2, R11.2, R13.2, R23.2, R25.2, U1.1 (IN), U1.3 (EN)

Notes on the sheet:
VIN 2.2V to 5.5V
IMU (ICM-20948)
I2C Level Shifting + Pullup Disconnects
Connections
Voltage Regulator
SPI / Interrupt Level Shifting
ADR -> I2C Address ------------------- open -> 0x69 closed -> 0x68 *Closing AD0 precludes SPI
Optionally disconnect the I2C pullup resistors on the primary and auxillary busses in case of too strong pullup from other sources
Cut to disable PWR LED
Address Option

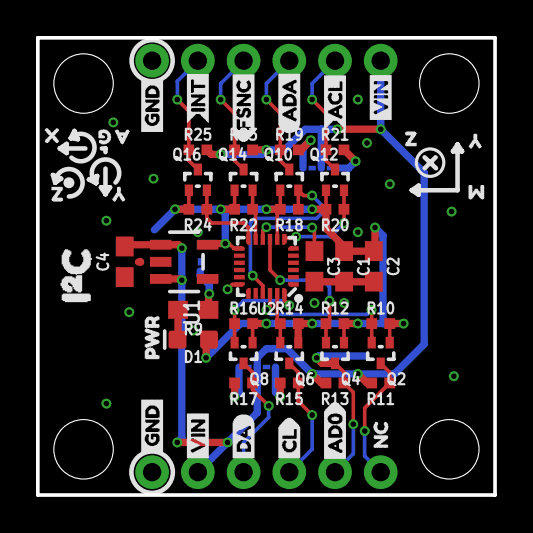
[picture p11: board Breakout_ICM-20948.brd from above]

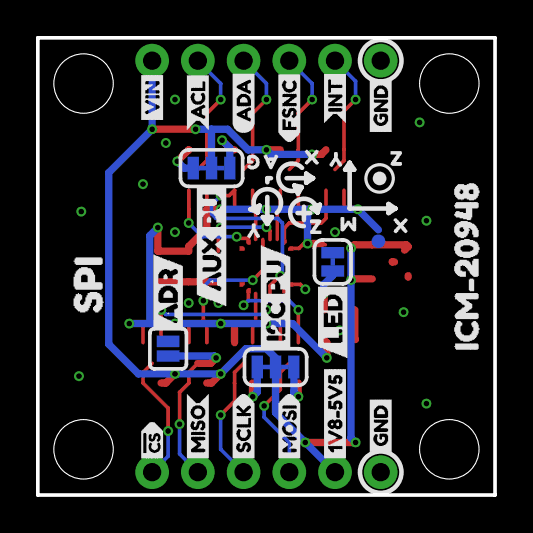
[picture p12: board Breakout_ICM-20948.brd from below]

Board: 2 copper layers, 25.4 x 25.4 mm, 92 parts (32 on the bottom side), 26 nets.

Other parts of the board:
U$1, U$2, U$22, U$24: GND4
U$3: PWR0
U$4, U$21: INT3
U$5, U$20: FSNC2
U$6, U$19: ACL1
U$7, U$18: ADA0
U$8: MISO13
U$9: MOSI14
U$10: SCLK15
U$11: #CS16
U$12: 1V8#5V57
U$13, U$30, U$44: VIN5
U$14: NC17
U$15: CL4
U$16: DA2
U$17: AD012
U$23: ADR2
U$25: I2C_PU21
U$26: SPI19
U$27: AUX_PU24
U$29: LED23
U$31: ICM#2094820
U$34, U$50, U$57: X0
U$35, U$41, U$51, U$58: Y1
U$36, U$42, U$52, U$59: Z2
U$37, U$60: G5
U$38, U$61: A4
U$39, U$49: M3
U$45: I#C1

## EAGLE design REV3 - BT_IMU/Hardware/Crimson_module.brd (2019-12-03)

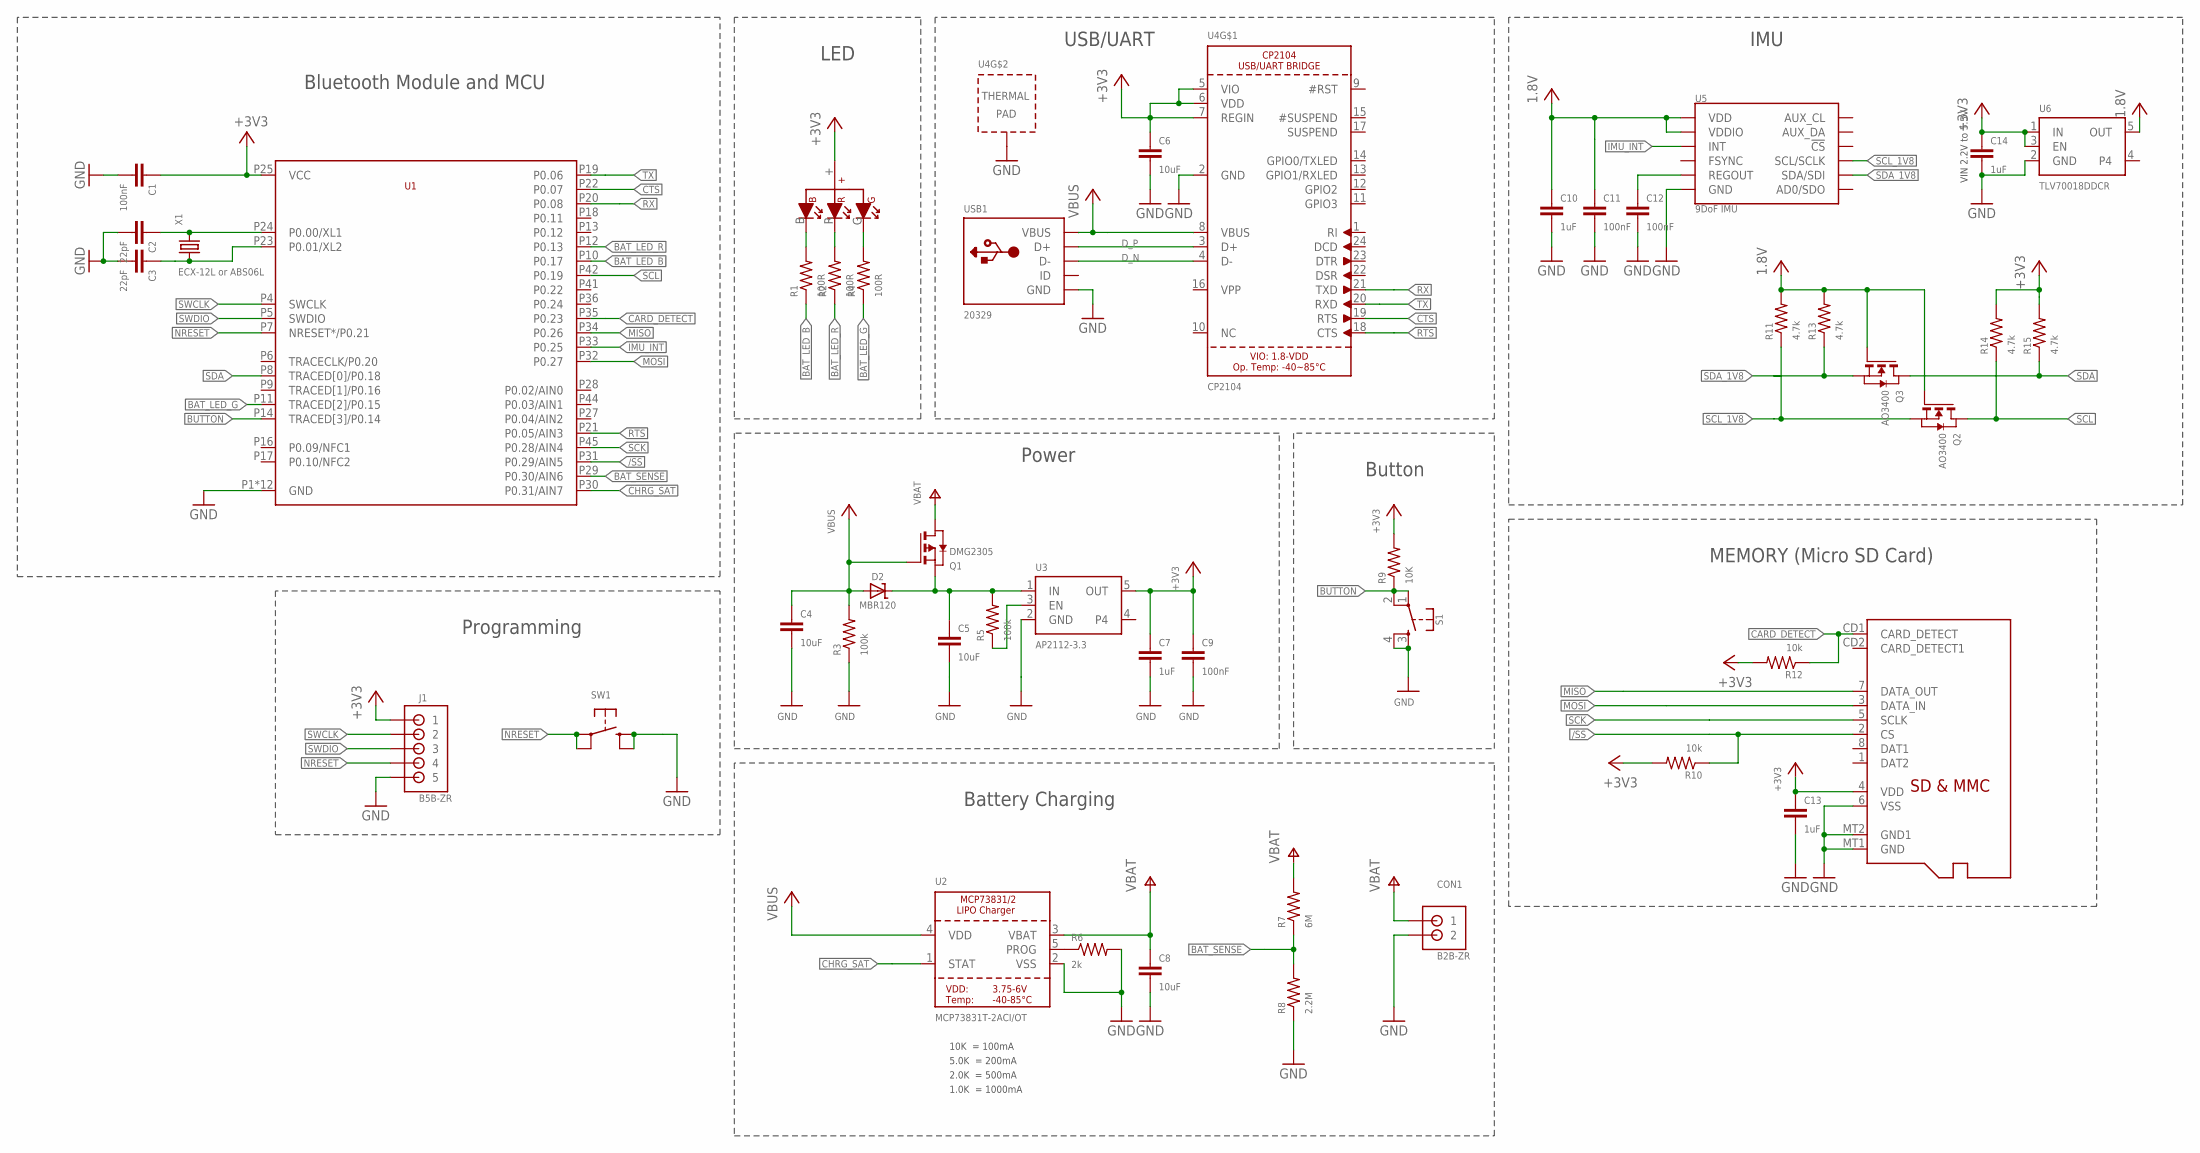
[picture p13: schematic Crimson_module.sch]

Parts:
C1, C9, C11, C12: 100nF; C0402
C2, C3: 22pF; C0402
C4, C5, C6, C8: 10uF; C0402
C7, C10, C13, C14: 1uF; C0402
CON1: B2B-ZR
D1: B2020RGBA
D2: MBR120; SOD-123
J1: B5B-ZR
Q1: DMG2305; SOT-23
Q2, Q3: AO3400; SOT-23
R1, R2, R4: 100R; R0402
R3, R5: 100k; R0402
R6: 2k; R0402
R7: 6M; R0402
R8: 2.2M; R0402
R9: 10K; R0402
R10, R12: 10k; R0402
R11, R13, R14, R15: 4.7k; R0402
S1: MOMENTARY-SWITCH-SPST-2-SMD-5.2MM; TACTILE_SWITCH_SMD_5.2MM
SD1: MICROSD
SW1: MICROBUILDER_SWITCH_TACT_SMT4.6X2.8; MICROBUILDER_BTN_KMR2_4.6X2.8
U1: BMD-350
U2: MCP73831T-2ACI/OT; SOT23-5
U3: AP2112-3.3; SOT23-5
U4: CP2104; QFN24_4MM_SMSC
U5: 9DoF IMU; QFN24-3X3
U6: TLV70018DDCR; MICROBUILDER_SOT23-5
USB1: 20329; 4UCONN_20329_V2
X1: ECX-12L or ABS06L; 2.0X1.2

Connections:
+3V3: C1.1, C6.1, C7.1, C9.1, C13.1, C14.1, D1.+, J1.1, R9.2, R10.2, R12.2, R14.2, R15.2, SD1.4 (VDD), U1.P25 (VCC), U3.5 (OUT), U4.5 (VIO), U4.6 (VDD), U4.7 (REGIN), U6.1 (IN), U6.3 (EN)
+5V: C4.1, D2.A, Q1.G, R3.2, U2.4 (VDD), U4.8 (VBUS), USB1.VBUS
/SS: R10.1, SD1.2 (CS), U1.P31 (P0.29/AIN5)
BAT_LED_B: R1.1, U1.P10 (P0.17)
BAT_LED_G: R4.1, U1.P11 (TRACED[2]/P0.15)
BAT_LED_R: R2.1, U1.P12 (P0.13)
BAT_SENSE: R7.1, R8.2, U1.P29 (P0.30/AIN6)
BUTTON: R9.1, S1.1, S1.2, U1.P14 (TRACED[3]/P0.14)
CARD_DETECT: R12.1, SD1.CD1 (CARD_DETECT), U1.P35 (P0.23)
CHRG_SAT: U1.P30 (P0.31/AIN7), U2.1 (STAT)
CTS: U1.P22 (P0.07), U4.19 (RTS)
D_N: U4.4 (D-), USB1.D-
D_P: U4.3 (D+), USB1.D+
EN: R5.1, U3.3 (EN)
GND: C1.2, C2.2, C3.2, C4.2, C5.2, C6.2, C7.2, C8.2, C9.2, C10.2, C11.2, C12.2, C13.2, C14.2, CON1.2, J1.5, R3.1, R6.2, R8.1, S1.3, S1.4, SD1.6 (VSS), SD1.MT1 (GND), SD1.MT2 (GND1), SW1.B (S), SW1.B' (S1), U1.P1 (GND), U1.P2 (GND), U1.P3 (GND), U1.P15 (GND), U1.P26 (GND), U1.P37 (GND), U1.P38 (GND), U1.P39 (GND), U1.P40 (GND), U1.P43 (GND), U1.P46 (GND), U1.P47 (GND), U2.2 (VSS), U3.2 (GND), U4.2 (GND), U4.THERM (TP), U5.18 (GND), U5.20 (GND), U6.2 (GND), USB1.BASE@1 (GND), USB1.BASE@2 (GND), USB1.GND, USB1.SPRT@1 (GND), USB1.SPRT@2 (GND), USB1.SPRT@3 (GND), USB1.SPRT@4 (GND)
IMU_INT: U1.P33 (P0.25), U5.12 (INT)
MISO: SD1.7 (DATA_OUT), U1.P34 (P0.26)
MOSI: SD1.3 (DATA_IN), U1.P32 (P0.27)
unnamed: R6.1, U2.5 (PROG)
unnamed: C12.1, U5.10 (REGOUT)
unnamed: C3.1, U1.P23 (P0.01/XL2), X1.1
unnamed: D1.B, R1.2
unnamed: D1.R, R2.2
unnamed: D1.G, R4.2
unnamed: C2.1, U1.P24 (P0.00/XL1), X1.2
unnamed: C5.1, D2.C, Q1.S, R5.2, U3.1 (IN)
NRESET: J1.4, SW1.A, SW1.A' (P1), U1.P7 (NRESET*/P0.21)
RTS: U1.P21 (P0.05/AIN3), U4.18 (CTS)
RX: U1.P20 (P0.08), U4.21 (TXD)
SCK: SD1.5 (SCLK), U1.P45 (P0.28/AIN4)
SCL: Q2.D, R14.1, U1.P42 (P0.19)
SCL_1V8: Q2.S, R11.1, U5.23 (SCL/SCLK)
SDA: Q3.D, R15.1, U1.P8 (TRACED[0]/P0.18)
SDA_1V8: Q3.S, R13.1, U5.24 (SDA/SDI)
SWCLK: J1.2, U1.P4 (SWCLK)
SWDIO: J1.3, U1.P5 (SWDIO)
TX: U1.P19 (P0.06), U4.20 (RXD)
V+: C8.1, CON1.1, Q1.D, R7.2, U2.3 (VBAT)
VCC: C10.1, C11.1, Q2.G, Q3.G, R11.2, R13.2, U5.8 (VDDIO), U5.13 (VDD), U6.5 (OUT)

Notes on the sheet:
10K = 100mA
5.0K = 200mA
2.0K = 500mA
1.0K = 1000mA
Battery Charging
Bluetooth Module and MCU
LED
USB/UART
Power
Button
MEMORY (Micro SD Card)
IMU
VIN 2.2V to 5.5V
Programming

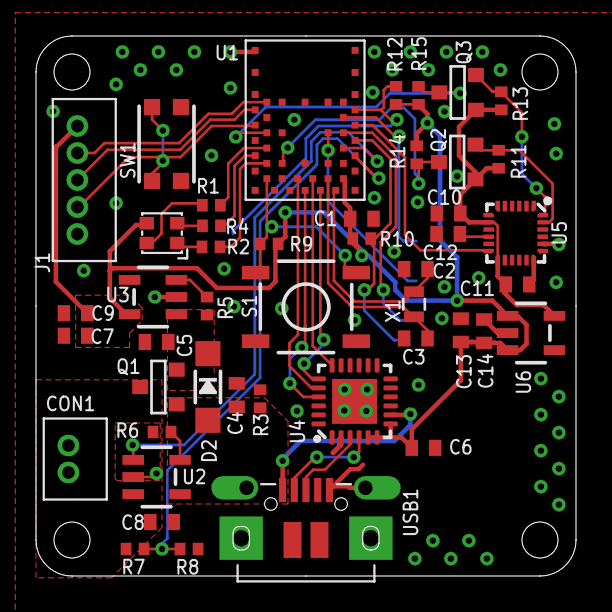
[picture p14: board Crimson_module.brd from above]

Board: 2 copper layers, 30.0 x 30.0 mm, 47 parts (1 on the bottom side), 39 nets.

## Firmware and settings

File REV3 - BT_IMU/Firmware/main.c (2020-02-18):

/**
 * Copyright (c) 2014 - 2019, Nordic Semiconductor ASA
 *
 * All rights reserved.
 *
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
 * 3. Neither the name of Nordic Semiconductor ASA nor the names of its
 *    contributors may be used to endorse or promote products derived from this
 *    software without specific prior written permission.
 *
 * 4. This software, with or without modification, must only be used with a
 *    Nordic Semiconductor ASA integrated circuit.
 *
 * 5. Any software provided in binary form under this license must not be reverse
 *    engineered, decompiled, modified and/or disassembled.
 *
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
 */
/** @file
 *
 * @defgroup ble_sdk_uart_over_ble_main main.c
 * @{
 * @ingroup  ble_sdk_app_nus_eval
 * @brief    UART over BLE application main file.
 *
 * This file contains the source code for a sample application that uses the Nordic UART service.
 * This application uses the @ref srvlib_conn_params module.
 */


#include <stdint.h>
#include <string.h>
#include "nordic_common.h"
#include "nrf.h"
#include "sdk_config.h"
#include "crimson_ble.h"
#include "app_timer.h"
#include "app_uart.h"
#include "app_util_platform.h"
#include "nrf_pwr_mgmt.h"

#include "nrf_drv_twi.h"
#include "nrf_delay.h"
#include "custom_board.h"
#include "nrf_queue.h"
#if defined (UART_PRESENT)
#include "nrf_uart.h"
#endif
#if defined (UARTE_PRESENT)
#include "nrf_uarte.h"
#endif

#include "nrf_log.h"
#include "nrf_log_ctrl.h"
#include "nrf_log_default_backends.h"

#include "nrf_drv_saadc.h"

#include "icm20948.h"
#include "crimson_sdcard.h"
#include "MadgwickAHRS.h"
#include "nrf_calendar.h"

extern uint32_t year, month, day, hour, minute, second;
extern volatile bool time_synced; 

#define ICM20948_ADDR 0x68

#define UART_TX_BUF_SIZE                256                                         /**< UART TX buffer size. */
#define UART_RX_BUF_SIZE                256                                         /**< UART RX buffer size. */
#define QUEUE_SIZE                      3

typedef enum arm_position{
    UP_POSITION,
    DOWN_POSITION,
    OTHER_POSITION
}arm_position;

arm_position previous_position; 

volatile bool log_available= false; 
volatile bool new_data_ready = false;
volatile bool m_xfer_done;

#define SAMPLES_IN_BUFFER 1
static nrf_saadc_value_t m_buffer[SAMPLES_IN_BUFFER];

#define TWI_INSTANCE_ID     0
nrf_drv_twi_t m_twi = NRF_DRV_TWI_INSTANCE(TWI_INSTANCE_ID);

#define IMU_SAMPLE_TIMER_INTERVAL     APP_TIMER_TICKS(100)     // 100 ms intervals 
APP_TIMER_DEF(imu_sample_timer_id);

float dt = 0.01; // time between two measurements 
float ax_accumulator, ay_accumulator, az_accumulator, gx_accumulator, gy_accumulator, gz_accumulator; //moving average filter accumulators

float angles[3]; // roll, pitch, yaw
float event_time= 12.3;
//circular buffer to store sensor data before running average filter
//the queue will overflow when it is full 
NRF_QUEUE_DEF(float, m_ax_queue, QUEUE_SIZE, NRF_QUEUE_MODE_OVERFLOW);
NRF_QUEUE_DEF(float, m_ay_queue, QUEUE_SIZE, NRF_QUEUE_MODE_OVERFLOW);
NRF_QUEUE_DEF(float, m_az_queue, QUEUE_SIZE, NRF_QUEUE_MODE_OVERFLOW);
NRF_QUEUE_DEF(float, m_gx_queue, QUEUE_SIZE, NRF_QUEUE_MODE_OVERFLOW);
NRF_QUEUE_DEF(float, m_gy_queue, QUEUE_SIZE, NRF_QUEUE_MODE_OVERFLOW);
NRF_QUEUE_DEF(float, m_gz_queue, QUEUE_SIZE, NRF_QUEUE_MODE_OVERFLOW);

//value to store the filtered sensor data 
float f_ax, f_ay, f_az, f_gx, f_gy, f_gz;
 
// calibration routine
bool calibrate(){
    // Turn on  LED configuration to indicate calibration (pink)
    nrf_gpio_pin_clear(LED_R);
    nrf_gpio_pin_clear(LED_B);

    // initialize running average filter accumulators
    for (int i=0; i<(QUEUE_SIZE-1); i++){
        ICM20948_read();
        ax_accumulator += _ax;
        ay_accumulator += _ay;
        az_accumulator += _az;
        gx_accumulator += _gx;
        gy_accumulator += _gy;
        gz_accumulator += _gz;

        //start filling up the queue
        ret_code_t err_code = nrf_queue_push(&m_ax_queue, &_ax);
        APP_ERROR_CHECK(err_code);
        err_code = nrf_queue_push(&m_ay_queue, &_ay);
        APP_ERROR_CHECK(err_code);
        err_code = nrf_queue_push(&m_az_queue, &_az);
        APP_ERROR_CHECK(err_code);
        err_code = nrf_queue_push(&m_gx_queue, &_gx);
        APP_ERROR_CHECK(err_code);
        err_code = nrf_queue_push(&m_gy_queue, &_gy);
        APP_ERROR_CHECK(err_code);
        err_code = nrf_queue_push(&m_gz_queue, &_gz);
        APP_ERROR_CHECK(err_code);

        //keep a rough 10Hz sampling frequency 
        nrf_delay_ms(10);
    }

    // determine initial gyro offset from average
    _gxb=gx_accumulator/((float)QUEUE_SIZE-1.0);
    _gyb=gy_accumulator/((float)QUEUE_SIZE-1.0);
    _gzb= gz_accumulator/((float)QUEUE_SIZE-1.0);
    
    printf("gyro bias: x: %f, y: %f, z: %f \n", _gxb, _gyb, _gzb);
    
    //init position
    previous_position = OTHER_POSITION;

    //calirate time
    while (!time_synced); // wait for time to sync


    //clear LEDs
    nrf_delay_ms(1000);
    nrf_gpio_pin_set(LED_R);
    nrf_gpio_pin_set(LED_B);
    NRF_LOG_INFO("calibration DONE!");

    return 1;
}

// Moving Average filter 
float moving_average(nrf_queue_t const * p_queue, float newest_value, float* accumulator){
    //read all values in the queue
    float m_average =0;
    float oldest_value;
    float acc = *accumulator;
    
   
    // when the queue is full
    if (nrf_queue_is_full(p_queue)){
        //add the new value to to the sum 
        
        acc = acc + newest_value;
        //divide by total size of queue
        m_average = acc / ((float)QUEUE_SIZE);
        
        //remove oldest value
        nrf_queue_pop(p_queue, &oldest_value);
        acc = acc - oldest_value;

    }
    //update accumulator value 
    *accumulator = acc;
    return m_average;
}

void process_position(float  roll, float pitch, float yaw){
    arm_position new_position; 

    if (pitch <= -50.0){
        // printf("down \t");
        new_position = DOWN_POSITION;
        // if the posiiton changed, log it 
            if (new_position != previous_position){
                log_available = true;                
                printf("DOWN\n");
            }   
    } else {
        if ((pitch>=-25) ||(roll>=0.0)){
            // printf("up \t");
            new_position= UP_POSITION; 
            // if the posiiton changed, log it 
            if (new_position != previous_position){
                log_available = true;
                printf("UP\n");

            }      
        }else{
            // printf("other \t");
            new_position = OTHER_POSITION;
        }
    }
    previous_position = new_position;
}

// timer event handler
static void timer_timeout_sensor_handler(void * p_context)
{
    //update sensor data 
    ICM20948_read();
   
    //store data in a queue
    ret_code_t err_code = nrf_queue_push(&m_ax_queue, &_ax);
    APP_ERROR_CHECK(err_code);
    err_code = nrf_queue_push(&m_ay_queue, &_ay);
    APP_ERROR_CHECK(err_code);
    err_code = nrf_queue_push(&m_az_queue, &_az);
    APP_ERROR_CHECK(err_code);
    err_code = nrf_queue_push(&m_gx_queue, &_gx);
    APP_ERROR_CHECK(err_code);
    err_code = nrf_queue_push(&m_gy_queue, &_gy);
    APP_ERROR_CHECK(err_code);
    err_code = nrf_queue_push(&m_gz_queue, &_gz);
    APP_ERROR_CHECK(err_code);

    //update running average filter
    f_ax=moving_average(&m_ax_queue, _ax, &ax_accumulator);
    f_ay=moving_average(&m_ay_queue, _ay, &ay_accumulator);
    f_az=moving_average(&m_az_queue, _az, &az_accumulator);
    f_gx=moving_average(&m_gx_queue, _gx, &gx_accumulator);
    f_gy=moving_average(&m_gy_queue, _gy, &gy_accumulator);
    f_gz=moving_average(&m_gz_queue, _gz, &gz_accumulator);
    
    // feed filtered data to Madgwick filter
    Madgwick_updateIMU(f_gx,f_gy, f_gz, f_ax, f_ay, f_az);
    computeAngles();

    // toggle flag
    new_data_ready = true;
}

/**@brief Function for initializing the timer module.
 */
static void timers_init(void)
{
    ret_code_t err_code = app_timer_init();
    APP_ERROR_CHECK(err_code);

    err_code = app_timer_create(&imu_sample_timer_id, APP_TIMER_MODE_REPEATED, timer_timeout_sensor_handler);
    APP_ERROR_CHECK(err_code);

}

/**@brief Function for starting timers.
*/
static void application_timers_start(void)
{
    app_timer_start(imu_sample_timer_id, IMU_SAMPLE_TIMER_INTERVAL, NULL);
}

void saadc_callback(nrf_drv_saadc_evt_t const * p_event)
{
    if (p_event->type == NRF_DRV_SAADC_EVT_DONE)
    {
        ret_code_t err_code;

        err_code = nrf_drv_saadc_buffer_convert(p_event->data.done.p_buffer, SAMPLES_IN_BUFFER);
        APP_ERROR_CHECK(err_code);
        
        // NRF_LOG_INFO("%d\r\n", p_event->data.done.p_buffer[0]);
        printf("%d\r\n", p_event->data.done.p_buffer[0]);

    }
}

void saadc_init()
{
    ret_code_t err_code;
    nrf_saadc_channel_config_t channel_config 
        = NRF_DRV_SAADC_DEFAULT_CHANNEL_CONFIG_SE(NRF_SAADC_INPUT_AIN6);

    err_code = nrf_drv_saadc_init(NULL, saadc_callback);
    APP_ERROR_CHECK(err_code);

    err_code = nrf_drv_saadc_channel_init(0, &channel_config);
    APP_ERROR_CHECK(err_code);

    err_code = nrf_drv_saadc_buffer_convert(m_buffer, SAMPLES_IN_BUFFER);
    APP_ERROR_CHECK(err_code);
}

/**
 * @brief TWI events handler.
 */
void twi_handler(nrf_drv_twi_evt_t const* p_event, void* p_context)
{
    switch (p_event->type) {
    case NRF_DRV_TWI_EVT_DONE:
        if (p_event->xfer_desc.type == NRF_DRV_TWI_XFER_RX) {
            //things you want to do with the data
        }
        m_xfer_done = true;
        break;
    default:
        break;
    }
}

void twi_init()
{
    ret_code_t err_code;

    const nrf_drv_twi_config_t twi_icm20948_config = {
        .scl = SCL_PIN,
        .sda = SDA_PIN,
        .frequency = NRF_DRV_TWI_FREQ_100K,
        .interrupt_priority = APP_IRQ_PRIORITY_HIGH,
        .clear_bus_init = false
    };

    err_code = nrf_drv_twi_init(&m_twi, &twi_icm20948_config, NULL, NULL);
    APP_ERROR_CHECK(err_code);

    nrf_drv_twi_enable(&m_twi);
}

/*
* Intermediary function to read registers
*/
ret_code_t read_register(nrf_drv_twi_t twi_instance, uint8_t device_addr, uint8_t register_addr, uint8_t* p_data, uint8_t bytes, bool no_stop)
{
    ret_code_t err_code;

    err_code = nrf_drv_twi_tx(&twi_instance, device_addr, &register_addr, 1, no_stop);
    APP_ERROR_CHECK(err_code);

    if (err_code != NRF_SUCCESS) {
        return err_code;
    }

    err_code = nrf_drv_twi_rx(&twi_instance, device_addr, p_data, bytes);
    return err_code;
}

/*@brief Function to read i2C sensor registers 
 * reads registers from ICM20948 given a starting register address, number of bytes, and a pointer to store data
*/
void readRegisters(uint8_t subAddress, uint8_t count, uint8_t *dest){
    ret_code_t err_code = read_register(m_twi, ICM20948_ADDR, subAddress, dest, count, true);
    APP_ERROR_CHECK(err_code);
}


/* writes a byte to ICM20948 register given a register address and data */
void  writeRegister(uint8_t subAddress, uint8_t data)
{
    /* write data to device */
    ret_code_t err_code;
    uint8_t reg[2] = {subAddress, data};
    err_code = nrf_drv_twi_tx(&m_twi, ICM20948_ADDR, reg, sizeof(reg), false);
    nrf_delay_ms(1);
    APP_ERROR_CHECK(err_code);
    // while (m_xfer_done == false);
}

/**@brief  Function for initializing the UART module.
 */
/**@snippet [UART Initialization] */
static void uart_init(void)
{
    uint32_t                     err_code;
    app_uart_comm_params_t const comm_params =
    {
        .rx_pin_no    = RX_PIN_NUMBER,
        .tx_pin_no    = TX_PIN_NUMBER,
        .rts_pin_no   = RTS_PIN_NUMBER,
        .cts_pin_no   = CTS_PIN_NUMBER,
        .flow_control = APP_UART_FLOW_CONTROL_DISABLED,
        .use_parity   = false,
#if defined (UART_PRESENT)
        .baud_rate    = NRF_UART_BAUDRATE_115200
#else
        .baud_rate    = NRF_UARTE_BAUDRATE_115200
#endif
    };

    APP_UART_FIFO_INIT(&comm_params,
                       UART_RX_BUF_SIZE,
                       UART_TX_BUF_SIZE,
                       uart_event_handle,
                       APP_IRQ_PRIORITY_LOWEST,
                       err_code);
    APP_ERROR_CHECK(err_code);
}
/**@snippet [UART Initialization] */


/**@brief Function for initializing the nrf log module.
 */
static void log_init(void)
{
    ret_code_t err_code = NRF_LOG_INIT(NULL);
    APP_ERROR_CHECK(err_code);

    NRF_LOG_DEFAULT_BACKENDS_INIT();
}


/**@brief Function for initializing power management.
 */
static void power_management_init(void)
{
    ret_code_t err_code;
    err_code = nrf_pwr_mgmt_init();
    APP_ERROR_CHECK(err_code);
}

/**@brief Function for handling the idle state (main loop).
 *
 * @details If there is no pending log operation, then sleep until next the next event occurs.
 */
// static void idle_state_handle(void)
// {
//     if (NRF_LOG_PROCESS() == false)
//     {
//         nrf_pwr_mgmt_run();
//     }
// }

static void rgb_led_init(){
    nrf_gpio_cfg_output (LED_G);
    nrf_gpio_cfg_output (LED_R);
    nrf_gpio_cfg_output (LED_B);

    nrf_gpio_pin_set(LED_G);
    nrf_gpio_pin_set(LED_R);
    nrf_gpio_pin_set(LED_B);
}

/**@brief Application main function.
 */
int main(void)
{
    // Initialize.
    uart_init();
    log_init();
    timers_init();
    twi_init();

    power_management_init();
    crimson_ble_init();
    rgb_led_init();

    // Start execution.
    printf("\r\nUART started.\r\n");
    NRF_LOG_INFO("Debug logging for UART over RTT started.");
       
    int val = ICM20948_init();
    if (val==0){
        printf("sensor OK \n");
    }

    sdcard_init();

    nrf_cal_init();
    saadc_init();
    calibrate();
    application_timers_start();
    
    Madgwick_init();
    Madgwick_setfreq(10.0); // frequency is 10Hz
    
    // Enter main loop.
    while (1)
    {
        if (new_data_ready){
            
            angles[0]= getRoll();
            angles[1]= getPitch();
            angles[2]= getYaw();
            
            // printf("Roll: %f , Pitch: %f , Yaw: %f \n ", angles[0], angles [1], angles[2]);
           
            process_position(angles[0], angles[1], angles[2]);
            new_data_ready=false; 
        }
        
        if (log_available){
            if (previous_position == UP_POSITION){
            sdcard_sensor_update_data( nrf_cal_get_time_string(false), 1);
            }
            if (previous_position == DOWN_POSITION){
            sdcard_sensor_update_data( nrf_cal_get_time_string(false),  0);
            }
            log_available = false;
        }
        
        // nrf_drv_saadc_sample();
        // // printf("batt: %d \n", m_buffer[0]);
        // nrf_delay_ms(10);
    }
}

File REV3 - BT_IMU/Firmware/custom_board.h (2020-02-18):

#ifndef CRIMSON_BOARD_H
#define CRIMSON_BOARD_H

#ifdef __cplusplus
extern "C" {
#endif //CRIMSON_BOARD_H

#include "nrf_gpio.h"
#define LEDS_NUMBER    3

#define LED_R 13
#define LED_G 15
#define LED_B 17

#define LEDS_ACTIVE_STATE 1

#define LEDS_INV_MASK  LEDS_MASK

#define LEDS_LIST { LED_R, LED_G, LED_B}

#define BSP_LED_0      LED_B
#define BSP_LED_1      LED_G
#define BSP_LED_2      LED_R



#define BUTTONS_NUMBER 1
#define BUTTONS_ACTIVE_STATE 0 

#define BUTTON_1 14

#define BUTTONS_LIST { BUTTON_1 }

#define BSP_BUTTON_0   BUTTON_1


#define RX_PIN_NUMBER  8
#define TX_PIN_NUMBER  6
#define CTS_PIN_NUMBER 7
#define RTS_PIN_NUMBER 5
#define HWFC           true

// #define SPIM0_SCK_PIN   28  // SPI clock GPIO pin number.
// #define SPIM0_MOSI_PIN  27  // SPI Master Out Slave In GPIO pin number.
// #define SPIM0_MISO_PIN  26  // SPI Master In Slave Out GPIO pin number.
// #define SPIM0_SS_PIN    29  // SPI Slave Select GPIO pin number.

#define SDC_SCK_PIN     28 //SDC serial clock (SCK) pin.
#define SDC_MOSI_PIN    27 //SDC serial data in (DI) pin.
#define SDC_MISO_PIN    26 //SDC serial data out (DO) pin.
#define SDC_CS_PIN      29 //SDC chip select (CS) pin.

#define SCL_PIN 19
#define SDA_PIN 18

#define IMU_INT_PIN 25
#define CARD_DETECT_PIN 23
#define BAT_SENSE_PIN 30 //AIN6

//stuff the NRF examples use and I can remove later

#define BUTTON_PULL    NRF_GPIO_PIN_PULLUP
#ifdef __cplusplus
}
#endif

#endif // 

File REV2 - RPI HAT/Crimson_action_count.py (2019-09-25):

#!/usr/bin/env python3
import time
import numpy as np
import matplotlib.pyplot as plt
from scipy.signal import find_peaks
from scipy.io import wavfile
from board import SCL, SDA
import busio
from PIL import Image, ImageDraw, ImageFont
import adafruit_ssd1306


def a_count():
    # Create the I2C interface for the screen
    i2c = busio.I2C(SCL, SDA)

    # Create the SSD1306 OLED class.
    disp = adafruit_ssd1306.SSD1306_I2C(128, 32, i2c)

    # Clear display.
    disp.fill(0)
    disp.show()

    # Create blank image for drawing.
    # Make sure to create image with mode '1' for 1-bit color.
    width = disp.width
    height = disp.height
    image = Image.new("1", (width, height))

    # Get drawing object to draw on image.
    draw = ImageDraw.Draw(image)

    # Draw a black filled box to clear the image.
    draw.rectangle((0, 0, width, height), outline=0, fill=0)

    # Draw some shapes.
    # First define some constants to allow easy resizing of shapes.
    padding = -2
    top = padding
    bottom = height - padding
    # Move left to right keeping track of the current x position for drawing shapes.
    x = 0

    # Load nice silkscreen font
    font = ImageFont.truetype("/home/pi/Desktop/Crimson/slkscr.ttf", 18)

    # Draw a black filled box to clear the image.
    draw.rectangle((0, 0, width, height), outline=0, fill=0)

    # Display RECORDING label on screen
    draw.text((x, top + 0), "PROCESSING...", font=font, fill=255)
    disp.image(image)
    disp.show()

    # recording/logging duration (in seconds)
    # This number can be found from the Crimson_thresing_test.py file
    t = 40

    # load data
    ax = np.genfromtxt("/home/pi/Desktop/Crimson/ax.csv", delimiter=",")
    ay = np.genfromtxt("/home/pi/Desktop/Crimson/ay.csv", delimiter=",")
    az = np.genfromtxt("/home/pi/Desktop/Crimson/az.csv", delimiter=",")

    fs, y = wavfile.read("/home/pi/Desktop/Crimson/output.wav")

    # width= , distance=20, prominence= , threshold=
    peaks_ax, _ = find_peaks(ax, prominence=0.75)
    peaks_ay, _ = find_peaks(ay, prominence=0.75)
    peaks_az, _ = find_peaks(az, prominence=0.75)
    peaks_mic, _ = find_peaks(y, height=2, distance=2000)

    # plotting
    fig = plt.figure()

    ax1 = fig.add_subplot(4, 1, 1)

    ax1.set(xticks=(np.arange(0, len(ax), len(ax) / t)), ylabel="Ax")
    ax1.set_xticklabels(np.arange(0, t, 1))

    ax2 = fig.add_subplot(4, 1, 2, sharex=ax1)
    ax2.set(ylabel="Ay")

    ax3 = fig.add_subplot(4, 1, 3, sharex=ax1)
    ax3.set(ylabel="Az")

    ax4 = fig.add_subplot(4, 1, 4)
    ax4.set(xticks=(np.arange(0, len(y), len(y) / t)), ylabel="MIC")
    ax4.set_xticklabels(np.arange(0, t, 1))

    ax1.plot(peaks_ax, ax[peaks_ax], "xr")
    ax1.plot(ax)
    ax2.plot(peaks_ay, ay[peaks_ay], "xr")
    ax2.plot(ay)
    ax3.plot(peaks_az, az[peaks_az], "xr")
    ax3.plot(az)
    ax4.plot(peaks_mic, y[peaks_mic], "xr")
    ax4.plot(y)

    # print(peaks_ax)
    # print(peaks_ay)
    # print(peaks_az)
    # print(peaks_mic)

    # convert peak values from sample number to time
    events_ax = (peaks_ax) * t / len(ax)
    # print(events_ax)
    events_ay = (peaks_ay) * t / len(ay)
    # print(events_ay)
    events_az = (peaks_az) * t / len(az)
    # print(events_az)
    events_mic = peaks_mic * t / len(y)
    # print(events_mic)

    # show plot
    # plt.show()

    # ------------------------------------#
    # signal preprocessing:
    # algo to determine if it's an action:

    # STEP 1:
    # In each signal average out cluster of peaks:
    # Assumption 1: sensor and microphone data for each drilling motion is close to a normal distribution,
    # the center of the motion should be close to the average value of x-coordinates
    # Therefore, to find the center we can calculate the average x-coordinate of a cluster of peaks
    # Assumption 2: there's at least 1 second in between two drilling actions

    # do it for ax
    peak_counter = 1
    avg_peaks = events_ax[0]
    avg_peaks_ax = []

    for i in range(1, len(events_ax)):
        # if two consecutive peaks are less than a second apart, add them up and increase the peak counter
        if (events_ax[i] - events_ax[i - 1]) <= 1:
            avg_peaks = avg_peaks + events_ax[i]
            peak_counter = peak_counter + 1

        # if the gap between two consecutive peaks is larger than 1s or the list of peaks is finished, log the average value of the group of peaks
        if ((events_ax[i] - events_ax[i - 1]) > 1) or (i == (len(events_ax) - 1)):
            # average the average peaks (yea I know it sounds redundant)
            avg_peaks = avg_peaks / peak_counter
            # add the averaged value to the ax valid peaks list
            avg_peaks_ax.append(avg_peaks)
            # put back the first non successive peak into the peak average value
            avg_peaks = events_ax[i]
            # reset peak counter
            peak_counter = 1

    # print(avg_peaks_ax)

    # do it for ay
    avg_peaks = events_ay[0]
    avg_peaks_ay = []

    for i in range(1, len(events_ay)):
        # if two consecutive peaks are less than a second apart, add them up and increase the peak counter
        if (events_ay[i] - events_ay[i - 1]) <= 1:
            avg_peaks = avg_peaks + events_ay[i]
            peak_counter = peak_counter + 1

        # if the gap between two consecutive peaks is larger than 1s or the list of peaks is finished, log the average value of the group of peaks
        if ((events_ay[i] - events_ay[i - 1]) > 1) or (i == (len(events_ay) - 1)):
            # average the average peaks (yea I know it sounds redundant)
            avg_peaks = avg_peaks / peak_counter
            # add the averaged value to the ax valid peaks list
            avg_peaks_ay.append(avg_peaks)
            # put back the first non successive peak into the peak average value
            avg_peaks = events_ay[i]
            # reset peak counter
            peak_counter = 1

    # print(avg_peaks_ay)

    # do it for az
    peak_counter = 1
    avg_peaks = events_az[0]
    avg_peaks_az = []

    for i in range(1, len(events_az)):
        # if two consecutive peaks are less than half a second apart, add them up and increase the peak counter
        if (events_az[i] - events_az[i - 1]) <= 1:
            avg_peaks = avg_peaks + events_az[i]
            peak_counter = peak_counter + 1
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

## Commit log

2019-07-26 Plotting single potentiometer data from Arduino
2019-08-12 Switch to raspi Zero W, plots IMU all 9 axes
2019-08-13 Working code with basic FF on accelerometer data
2019-09-07 Working prototype of recording data, peak finding and action matching
2019-09-07 added test data
    [ax.csv, ay.csv, az.csv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]
2019-09-18 Added rev2 Hardware files
    [Crimson_HAT_BOM.xlsx, Crimson_rev2.brd, Crimson_rev2.sch]
2019-12-03 PCB files for IMU dev board
    [BT_IMU_Crimson_BOM.xlsx, Crimson_module.brd, Crimson_module.sch]
2020-01-27 timer, led, ble, i2c to sensor
2020-02-12 sensor up/dpwn stable
2020-08-12 Post project commit
    [BT_IMU_Crimson_BOM.xlsx, Breakout_ICM-20948.brd, Breakout_ICM-20948.sch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]

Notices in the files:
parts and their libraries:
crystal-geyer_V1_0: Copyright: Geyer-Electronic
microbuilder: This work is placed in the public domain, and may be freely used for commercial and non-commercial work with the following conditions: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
